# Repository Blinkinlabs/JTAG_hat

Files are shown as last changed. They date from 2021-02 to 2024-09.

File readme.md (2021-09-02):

# JTAG Hat

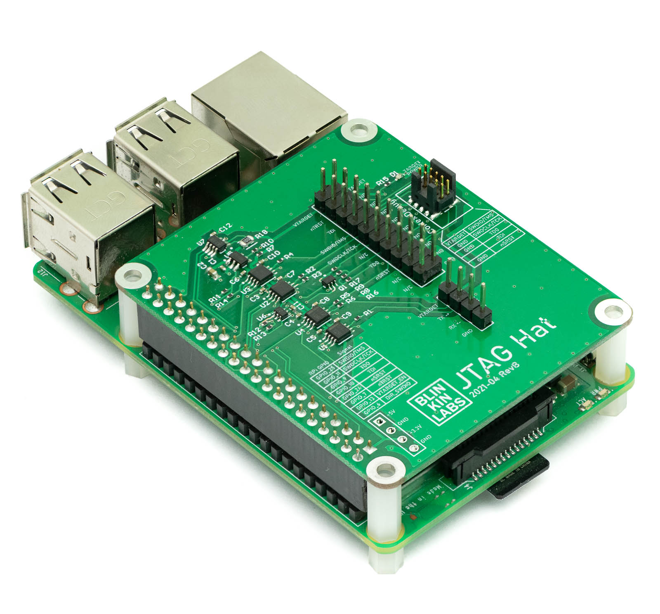
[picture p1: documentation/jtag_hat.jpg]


Convert your Raspberry Pi 2/3/4 into a networked JTAG debugger!

The JTAG Hat is designed to work with [OpenOCD](http://openocd.org/), and provides a .05" 10-pin [Cortex Debug Connector](https://documentation-service.arm.com/static/5fce6c49e167456a35b36af1), with pins to support debugging devices with either a JTAG (TCK/TMS/TDI/TDO) or SWD (SWDIO/SWDCLK) programming interface. A traditional .1, 20-pin JTAG header is also provided, which can be used with 0.1" jumper wires for more flexibiity.

Features:
*    Level-shifted JTAG / SWD programming interface, supports 1.8V to 5V targets
*    Designed to work with OpenOCD, which supports debugging a large number of devices (STM32, ESP32, etc)
*    Selectable target power, to power your device from the RPi 3.3V suppy
*    Hardware reset (both SRST and TRST) via a pull-down transistor
*    Level-shifted UART interface connected to RPi serial port
*    Built-in voltage and current measurement of target device

[Get one here (US)](https://shop.blinkinlabs.com/collections/development-tools/products/jtag-hat) or [here (EU/rest of world)](https://shop-nl.blinkinlabs.com/collections/development-tools/products/jtag-hat), or make one yourself- all design files are in this repository.

## Setup

1. Use [Rasbperry Pi Imager](https://www.raspberrypi.org/software/) to image the micro SD card with 'Raspberry Pi OS Lite'

2. Before clicking 'write', enter the secret 'advanced options' menu by holding down Ctrl+Shift+X. Change the following settings:
   1. Set the hostname to 'jtaghat'
   2. Enable SSH, and set a password for the 'pi' user
   3. Enable WiFi, and set the SSID and password for your WiFi netowrk. Set the Wifi country to your country.
   4. Set the locale settings to your current location.
   5. Check the option to skip the first-run wizard.

2. Boot the pi, and check the router to determine the IP address, then SSH into it

3. Update packages and install git:
```
sudo apt update
sudo apt upgrade -y
sudo apt install -y git autoconf libtool libusb-1.0-0-dev screen telnet
```

4. Download and build the master branch of OpenOCD:
```
git clone https://git.code.sf.net/p/openocd/code openocd-code
cd openocd-code

./bootstrap
./configure --enable-sysfsgpio --enable-bcm2835gpio
make -j6
sudo make install
```

## Use it

1. Connect using the Arm Cortex Debug connector
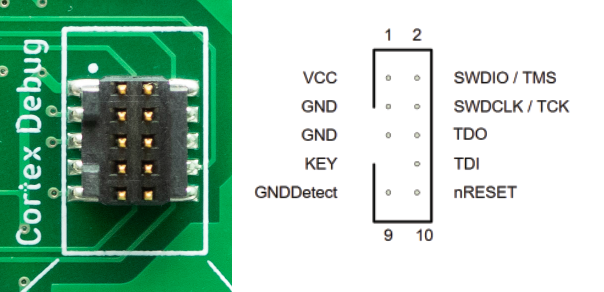
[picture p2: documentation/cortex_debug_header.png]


This connector works well if your target board has one of these connectors. This connector supports both JTAG and SWD connection modes, and has a reset pin controlled by 'srst'. It's very tidy:

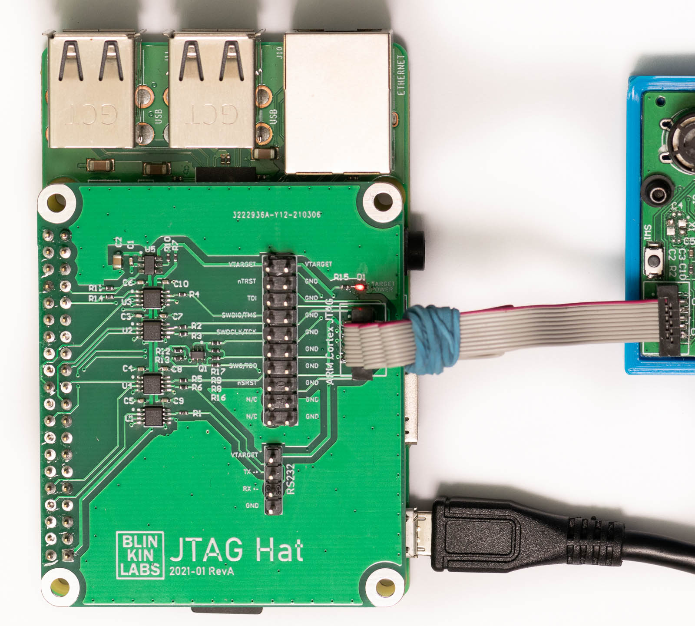
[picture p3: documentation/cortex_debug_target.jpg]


-or-

2.  Connect using the 20-pin 'legacy' connector
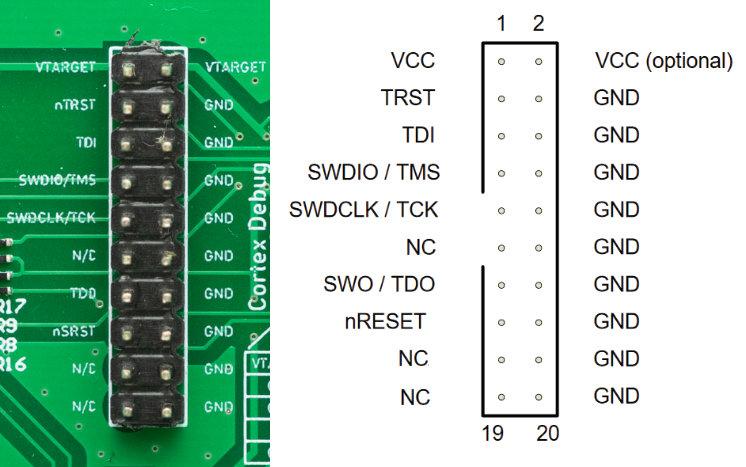
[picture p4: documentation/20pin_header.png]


This connector works well if your target board has one of these connectors, or if you want to use jumper wires to connect to .1" headers on a board. This connector supports both JTAG and SWD connection modes, and has a reset pin controlled by 'srst', as well as one  controlled by 'trst'. Note that some of the optional signals (RTCK, DBGRQ, DBACK) are not supported by OpenOCD, and are not present on this connector.

For SWD mode, you'll need at least GND,SWDIO, and SWDCLK. For JTAG mode, you'll need GND,TCK,TDI,TDO, and TMS.

3. (optional) Enable target power

The JTAG Hat can provide an optional 3.3V, 500mA* supply to the target. To enable it, RPi GPIO13 should be set to an output:
```
echo 13 > /sys/class/gpio/export
echo out > /sys/class/gpio/gpio13/direction
echo 1 > /sys/class/gpio/gpio13/value
```

Similarly, to turn it off:
```
echo 0 > /sys/class/gpio/gpio13/value
```
Note: If your target board is already powered, do not enable target power! The red LED on the board will light up when the target power voltage is present.

4. Start an OpenOCD session for an STM32F0 target:
```
sudo openocd -f interface/jtag_hat_rpi2.cfg \
             -c "bindto 0.0.0.0; transport select swd" \
             -c "reset_config srst_only" \
             -c "adapter speed 1000" \
             -f target/stm32f0x.cfg
```

Now you can connect to the server using GDB, and flash new code, dump things, etc.

## Sensing load current

The hat includes an INA219 current sensor, which can be used to monitor the target power usage if powered through the Pi, and the target voltage if the target is self-powered. To use it:

1. Use 'sudo raspi-config', and under the 'Interfacing Options' menu, enable the I2C interface.

2. Install the [Pi INA219 library](https://github.com/chrisb2/pi_ina219/blob/master/README.md):
```
    sudo apt install python3-pip
    pip3 install pi-ina219
```

3. Create a new file called 'sense_current.py', and copy the following into it:

```
#!/usr/bin/env python3
from ina219 import INA219
from ina219 import DeviceRangeError
SHUNT_OHMS = 0.1
def read():
   ina = INA219(SHUNT_OHMS)
   ina.configure()
   print("Bus Voltage: {:.3f} V".format(ina.voltage()))
   try:
       print("Bus Current: {:.3f} mA".format(ina.current()))
       print("Power: {:.3f} mW".format(ina.power()))
       print("Shunt voltage: {:.3f} mV".format(ina.shunt_voltage()))
   except DeviceRangeError as e:
       # Current out of device range with specified shunt resister
       print(e)
if __name__ == "__main__":
   read()
```

4. Make the script executable, then run it:
```
chmod +x sense_current.py
./sense_current.py
    
Bus Voltage: 3.280 V
Bus Current: 95.000 mA
Power: 311.707 mW
Shunt voltage: 9.510 mV
```

Note that the current measurement includes the power used by the target voltage indicator LED, as well as the level translation buffers.

## UART header

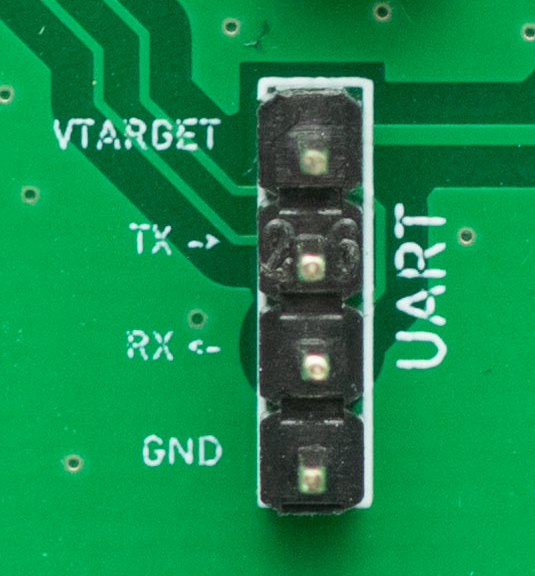
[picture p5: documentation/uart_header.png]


The JTAG Hat also has a level-translated UART header. The UART situation on Raspberry Pi is a [little complicated](https://www.raspberrypi.org/documentation/configuration/uart.md), so a little configuration is needed to make this pin work.

### Setup

1. Disable Bluetooth (Raspberry Pi 3,4 only): On the Raspberry Pi 3 and 4, the UART is normally connected to the Bluetooth chip, so we'll first need to disable that to free up the pins. Add the following to /boot/config.txt:
```
dtoverlay=disable-bt
```
2. Enable the serial port and configure it for general purpose use. Run 'sudo raspi-config', then select '3 Interface Options', 'P6 Serial Port'. Choose 'No' to disable the login shell over serial, then 'Yes' to enable hardware serial. Choose 'Ok' to confirm the settings, then 'Finish' to apply them. Choose 'Yes' to reboot the system and apply the changes.

3. Once the system reboots, check that the serial port is configured correctly:
```
ls -l /dev/serial0
```
This should now point to ttyAM0:
```
lrwxrwxrwx 1 root root 7 Mar 24 15:10 /dev/serial0 -> ttyAMA0
```

### Using the serial port

Once the serial port is configured, it should be ready for use. You can test it using screen:
```
screen /dev/serial0 115200
```

Tip: Make sure to connect a ground wire between the JTAG Hat and the target board.

Tip: Make sure Vtarget is enabled, otherwise the serial port buffers won't work.

## Hardware design

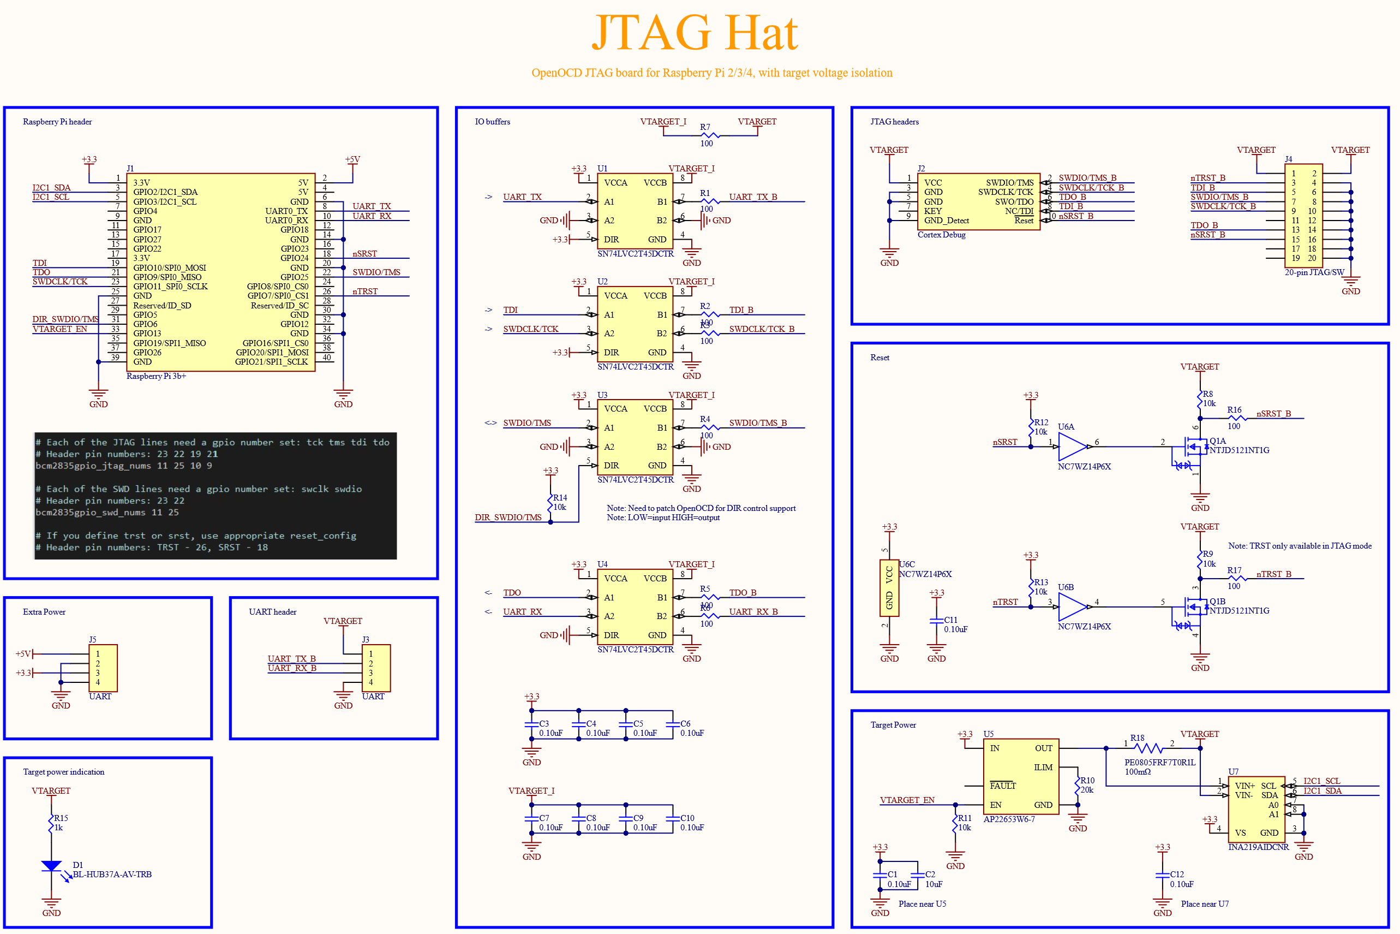
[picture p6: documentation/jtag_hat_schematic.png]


This repository contains the Altium [source files](https://github.com/Blinkinlabs/JTAG_hat/tree/main/pcb), as well as the gerbers used for production.

## License

Copyright Blinkinlabs 2021. The board design is [licensed under CERN-OHL-P v2](https://cern.ch/cern-ohl) and documentation is released under [Attribution-ShareAlike 4.0 International](https://creativecommons.org/licenses/by-sa/4.0/legalcode)

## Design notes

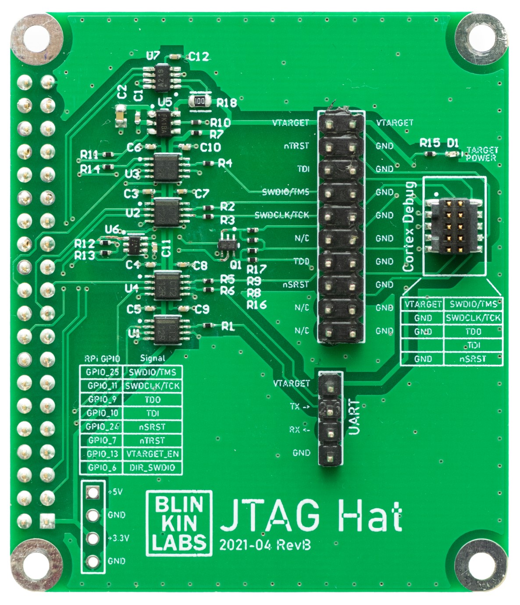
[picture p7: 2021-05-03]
documentation/jtag_hat_top_view.jpg

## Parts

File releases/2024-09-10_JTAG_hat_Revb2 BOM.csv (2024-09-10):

Designator | Quantity | Comment | Description | Manufacturer 1 | Manufacturer Part Number 1 | Supplier 1 | Supplier Part Number 1 | Supplier 2 | Supplier Part Number 2 | Pins | Package / Case | Footprint | Library Name
C1, C3, C4, C5, C6, C7, C8, C9, C10, C11, C12 | 11 | 0.10uF | CAP CER 0.1UF 16V X5R 0402 | Murata | GRM155R61C104KA88D | Digikey | 490-5415-1-ND |  |  | 2 |  | CAPC1005X06L | blinkinlabs.DbLib
C2 | 1 | 10uF | CAP CER 10UF 10V X7R 0805 | Murata Electronics North America | GRM21BR71A106KE51L | DigiKey | 490-3905-1-ND |  |  | 2 |  | CAPC2012X10L | blinkinlabs.DbLib
D1 | 1 | BL-HUB37A-AV-TRB | LED, 0402, Super Red, 50mcd@20mA, 627~637nm | BrtLed | BL-HUB37A-AV-TRB | LCSC | C165980 |  |  | 2 |  | BL-Hxx37A-AV-TRB | blinkinlabs.DbLib
J1 | 1 | SC0073 | Raspberry Pi shield Header | Raspberry Pi | SC0073 | Digikey | 2648-SC0073-ND |  |  | 40 |  | RaspberryPi_Connector | blinkinlabs.DbLib
J2 | 1 | FTSH-105-01-L-DV-K-TR | 1.27mm 2 10P -55?~+125? Standing paste 3.4A SMD,P=1.27mm Board-to-Board and Backplane Connector ROHS | Samtec | FTSH-105-01-L-DV-K-TR | LCSC | C448647 | Digikey | SAM13165CT-ND | 10 |  | FTSH-105-01-L-DV-K-TR | blinkinlabs.DbLib
Q1 | 1 | NTJD5121NT1G | Mosfet Array 60V 295mA 250mW Surface Mount SC-88/SC70-6/SOT-363 | ON Semiconductor | NTJD5121NT1G | Digikey | NTJD5121NT1GOSCT-ND | LCSC | C15215 | 6 |  | FP-419B-02-MFG | blinkinlabs.DbLib
R1, R2, R3, R4, R5, R6, R7, R16, R17 | 9 | 100 | RES SMD 100 OHM 5% 1/10W 0402 | Panasonic | ERJ-2GEJ101X | DigiKey | P100JCT-ND |  |  | 2 |  | ERJ2G(0402)_L | blinkinlabs.DbLib
R8, R9, R11, R12, R13, R14 | 6 | 10k | RES SMD 10K OHM 5% 1/5W 0402 | Panasonic | ERJ-PA2J103X | Digikey | P17199CT-ND |  |  | 2 |  | ERJ2G(0402)_L | blinkinlabs.DbLib
R10 | 1 | 20k | RES SMD 20K OHM 1% 1/10W 0402 | Panasonic Electronic Components | ERJ-2RKF2002X | Digikey | P20.0KLCT-ND |  |  | 2 |  | ERJ2G(0402)_L | blinkinlabs.DbLib
R15 | 1 | 1k | RES SMD 1K OHM 5% 1/10W 0402 | Panasonic | ERJ2GEJ102X- | Digikey | P1.0KJCT-ND |  |  | 2 |  | ERJ2G(0402)_L | blinkinlabs.DbLib
R18 | 1 | CS05W4F100LT5E | 250mW Thick Film Resistors 500V ±1% 100mO 0805 Chip Resistor - Surface Mount ROHS | UNI-ROYAL | CS05W4F100LT5E | LCSC | C474291 |  |  | 2 |  | ERJ6G(0805)_N | blinkinlabs.DbLib
U1, U2, U3, U4 | 4 | SN74LVC2T45DCTR | Voltage Level Translator Bidirectional 1 Circuit 2 Channel 420Mbps SM8 | Texas Instruments | SN74LVC2T45DCTR | Digikey | 296-16845-1-ND | LCSC | C22672 | 8 |  | FP-DCT0008A-MFG | blinkinlabs.DbLib
U5 | 1 | AP22653W6-7 | LOAD SWITCH,SOT26,T&R,3K | Diodes | AP22653W6-7 | Digikey | 31-AP22653W6-7TR-ND | LCSC | C2158037 | 6 |  | SOT95P280X145-6N-5 | blinkinlabs.DbLib
U6 | 1 | NC7WZ14P6X | Inverter IC 2 Channel Schmitt Trigger SC-88 (SC-70-6) | ON Semiconductor / Fairchild | NC7WZ14P6X | DigiKey | NC7WZ14P6XCT-ND | LCSC | C19829571 | 6 |  | TSOP65P210X110-6N | blinkinlabs.DbLib
U7 | 1 | INA219AID | Current Monitor Regulator High-Side 10mA 8-SOIC | Texas Instruments | INA219AID | Digikey | 296-33291-5-ND | LCSC | C138706 | 8 |  | D0008A_N | blinkinlabs.DbLib
J3 | 1 | UART | Header, 4-Pin |  |  |  |  |  |  | 4 |  | HDR1X4 | Miscellaneous Connectors.IntLib
J4 | 1 | 20-pin JTAG/SW |  |  |  |  |  |  |  | 20 |  | HDR2X10 | Miscellaneous Connectors.IntLib
J5 | 1 | POWER | Header, 4-Pin |  |  |  |  |  |  | 4 |  | HDR1X4 | Miscellaneous Connectors.IntLib

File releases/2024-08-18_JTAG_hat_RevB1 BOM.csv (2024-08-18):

Designator | Quantity | Comment | Description | Manufacturer 1 | Manufacturer Part Number 1 | Supplier 1 | Supplier Part Number 1 | Supplier 2 | Supplier Part Number 2 | Pins | Package / Case | Footprint | Library Name
Q1 | 1 | NTJD5121NT1G | MOSFET 2N-CH 60V 0.295A SOT363 |  |  |  |  |  |  | 6 |  | FP-419B-02-MFG | Altium Content Vault
R18 | 1 | PE0805FRF7T0R1L | METAL CURRENT SENSOR 0805 1% 100 | Yageo | PE0805FRF7T0R1L | Farnell | 4149061 | Farnell | 4149061RL | 2 |  | FP-PE0805L-0R051-0R910-MFG | Altium Content Vault
U1, U2, U3, U4 | 4 | SN74LVC2T45DCTR | IC TRNSLTR BIDIRECTIONAL SM8 | Texas Instruments | SN74LVC2T45DCTR | Digikey | 296-16845-1-ND | Digikey | 296-16845-2-ND | 8 |  | FP-DCT0008A-MFG | Altium Content Vault
U6 | 1 | NC7WZ14P6X | Tiny Logic(R) UHS Dual Inverter with Schmitt Trigger Inputs, 1.65 to 5.5 V, -40 to 85 degC, 6-Pin SOT23 (SC70), RoHS, Tape and Reel | ON Semiconductor / Fairchild | NC7WZ14P6X | Farnell | 1417668 | Farnell | 1417668RL | 6 | 6-TSSOP,SC-88,SOT-363 | FAIR-SC70-6_V | Altium Content Vault
U7 | 1 | INA219AID | Zero-Drift, Bi-Directional Current / Power Monitor, 3 to 5.5 V, -40 to 125 degC, 8-pin SOIC (D8), Green (RoHS & no Sb/Br) | Texas Instruments | INA219AID | Digikey | 296-33291-5-ND | Mouser | 595-INA219AID | 8 |  | D0008A_N | Altium Content Vault
D1 | 1 | BL-HUB37A-AV-TRB | LED, 0402, Super Red, 50mcd@20mA, 627~637nm |  |  |  |  |  |  | 2 |  | BL-Hxx37A-AV-TRB | Blinkinlabs.IntLib
J1 | 1 | Raspberry Pi 3b+ | Raspberry Pi shield Header |  |  |  |  |  |  | 40 |  | RaspberryPi_Connector | Blinkinlabs.IntLib
J2 | 1 | Cortex Debug | Arm Cortex 10-pin JTAG connector |  |  |  |  |  |  | 10 |  | 1.27mm 2x5 SMD Header | Blinkinlabs.IntLib
U5 | 1 | AP22653W6-7 | LOAD SWITCH,SOT26,T&R,3K |  |  |  |  |  |  | 6 |  | SOT95P280X145-6N-5 | Blinkinlabs.IntLib
C1, C3, C4, C5, C6, C7, C8, C9, C10, C11, C12 | 11 | 0.10uF | CAP CER 0.1UF 10V X5R 0402 |  |  |  |  |  |  | 2 | 0402 (1005 Metric) | CAPC1005X06L | cap_murata.DbLib
C2 | 1 | 10uF | CAP CER 10UF 10V X7R 0805 |  |  |  |  |  |  | 2 | 0805 (2012 Metric) | CAPC2012X10L | cap_murata.DbLib
J3, J5 | 2 | UART | Header, 4-Pin |  |  |  |  |  |  | 4 |  | HDR1X4 | Miscellaneous Connectors.IntLib
J4 | 1 | 20-pin JTAG/SW |  |  |  |  |  |  |  | 20 |  | HDR2X10 | Miscellaneous Connectors.IntLib
R1, R2, R3, R4, R5, R6, R7, R16, R17 | 9 | 100 | RES SMD 100 OHM 5% 1/10W 0402 |  |  |  |  |  |  | 2 | 0402 (1005 Metric) | ERJ2G(0402)_L | res_panasonic_erj_xls.DbLib
R8, R9, R11, R12, R13, R14 | 6 | 10k | RES SMD 10K OHM 5% 1/5W 0402 |  |  |  |  |  |  | 2 | 0402 (1005 Metric) | ERJ2G(0402)_L | res_panasonic_erj_xls.DbLib
R10 | 1 | 20k | RES SMD 20K OHM 1% 1/10W 0402 |  |  |  |  |  |  | 2 | 0402 (1005 Metric) | ERJ2G(0402)_L | res_panasonic_erj_xls.DbLib
R15 | 1 | 1k | RES SMD 1K OHM 5% 1/10W 0402 |  |  |  |  |  |  | 2 | 0402 (1005 Metric) | ERJ2G(0402)_L | res_panasonic_erj_xls.DbLib

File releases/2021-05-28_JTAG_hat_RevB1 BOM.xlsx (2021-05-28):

Designator | Comment | Manufacturer | PartNumber | Digi-Key Part Number | LCSC PartNumber | Description | Pins | Quantity | Model:Footprint | Case/Package
C1, C3, C4, C5, C6, C7, C8, C9, C10, C11, C12 | 0.10uF | Murata Electronics North America | GRM155R61A104KA01D | 490-1318-1-ND |  | CAP CER 0.1UF 10V X5R 0402 | 2 | 11 |  | 0402
C2 | 10uF | Murata Electronics North America | GRM21BR71A106KE51L | 490-3905-1-ND |  | CAP CER 10UF 10V X7R 0805 | 2 | 1 |  | 0805
D1 | BL-HUB37A-AV-TRB | BrtLed(佰鸿) | BL-HUB37A-AV-TRB |  | C165980 | LED, 0402, Super Red, 50mcd@20mA, 627~637nm | 2 | 1 | 0402 LED, generic
J1 | Raspberry Pi 3b+ |  |  |  |  | Raspberry Pi shield Header | 40 | 1
J2 | Cortex Debug | Unknown/Generic | unknown/Generic |  |  | Arm Cortex 10-pin JTAG connector | 10 | 1
J3, J5 | UART |  |  |  |  | Header, 4-Pin | 4 | 2 | Connector; Header; 4 Position
J4 | 20-pin JTAG/SW |  |  |  |  |  | 20 | 1 | Connector; Header; 10x2 Position
Q1 | NTJD5121NT1G | On Semiconductor |  |  |  | MOSFET 2N-CH 60V 0.295A SOT363 | 6 | 1
R1, R2, R3, R4, R5, R6, R7, R16, R17 | 100 | Panasonic Electronic Components | ERJ-2GEJ101X | P100JCT-ND |  | RES SMD 100 OHM 5% 1/10W 0402 | 2 | 9 |  | 0402
R8, R9, R11, R12, R13, R14 | 10k | Panasonic Electronic Components | ERJ-PA2J103X | P17199CT-ND |  | RES SMD 10K OHM 5% 1/5W 0402 | 2 | 6 |  | 0402
R10 | 20k | Panasonic Electronic Components | ERJ-2RKF2002X | P20.0KLCT-ND |  | RES SMD 20K OHM 1% 1/10W 0402 | 2 | 1 |  | 0402
R15 | 1k | Panasonic Electronic Components | ERJ-2GEJ102X | P1.0KJCT-ND |  | RES SMD 1K OHM 5% 1/10W 0402 | 2 | 1 |  | 0402
R18 | PE0805FRF7T0R1L | Yageo |  |  |  | METAL CURRENT SENSOR 0805 1% 100 | 2 | 1
U1, U2, U3, U4 | SN74LVC2T45DCTR | Texas Instruments |  |  |  | IC TRNSLTR BIDIRECTIONAL SM8 | 8 | 4
U5 | AP22653W6-7 | Diodes Incorporated | AP22653W6-7 |  |  | LOAD SWITCH,SOT26,T&R,3K | 6 | 1 | SOT23, 6-Leads, Body 2.90x2.80mm, Pitch 0.95mm, IPC Medium Density
U6 | NC7WZ14P6X | Fairchild Semiconductor |  |  |  | Tiny Logic(R) UHS Dual Inverter with Schmitt Trigger Inputs, 1.65 to 5.5 V, -40 to 85 degC, 6-Pin SOT23 (SC70), RoHS, Tape and Reel | 6 | 1 | SC70, 6-Leads, Body 2x1.25mm, Pitch 0.65mm
U7 | INA219AID | Texas Instruments | INA219AID |  |  | Zero-Drift, Bi-Directional Current / Power Monitor, 3 to 5.5 V, -40 to 125 degC, 8-pin SOIC (D8), Green (RoHS & no Sb/Br) | 8 | 1 | SOIC, 8-Leads, Body 5x4mm, Pitch 1.27mm, IPC Medium Density

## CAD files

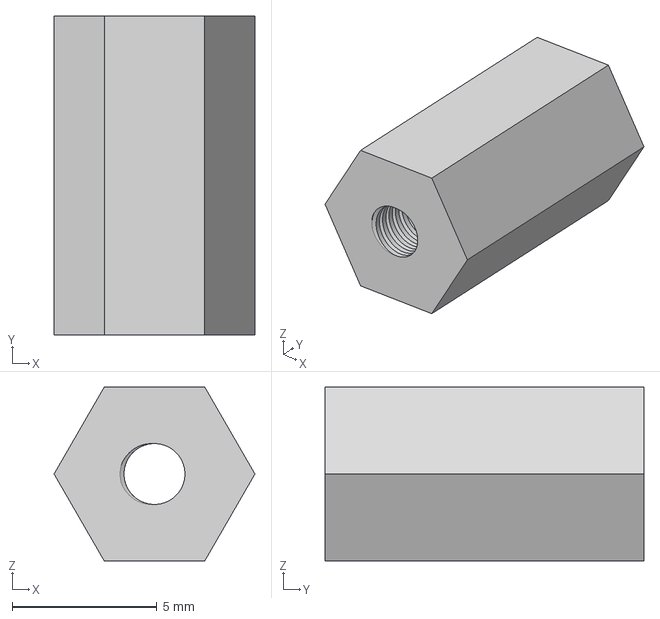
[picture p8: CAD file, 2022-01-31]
releases/2022-01-30 spacer.3mf
6.93 x 11.0 x 6.00 mm

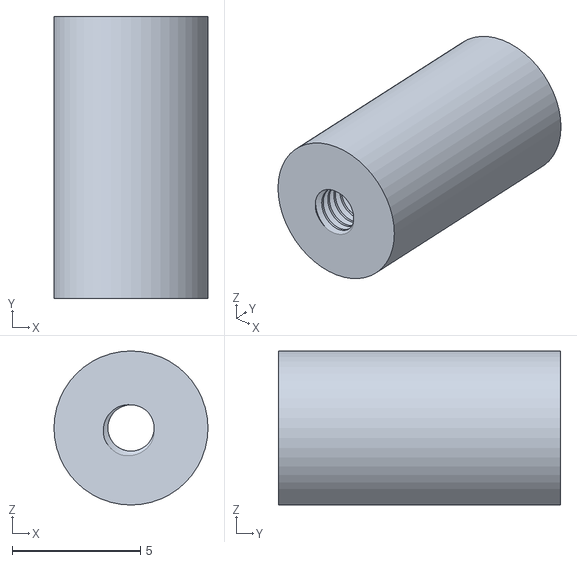
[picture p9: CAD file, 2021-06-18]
releases/2021-05-27_spacer.STL
6.00 x 11.0 x 6.00

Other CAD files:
releases/2022-01-30 spacer v1.f3d

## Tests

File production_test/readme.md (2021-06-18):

# Production test

Script to test that all features of the JTAG-Hat are functional

Required material:

* Raspberry Pi w/patched OpenOCD
* JTAG_Hat (DUT)
* STM32F103RC development board, or board with similar processor that supports both JTAG and SWD programming interfaces
* 2x LED + ~330 ohm resistor, connected in series. Attach one between 3.3V and SRST on the development board, and the other between 3.3V and TRST on the develoment board.
* 10-pin, 1.27mm ribbon cable
* 20-pin 2.54mm ribbon cable
* 20-pin to 10-pin adapter board (if development board only has 20-pin interface)
* 2-pin, 2.54mm jumper

Steps:

1. Boot the raspberry pi
2. Plug a JTAG Hat into the raspberry pi
3. Connect the 2-pin jumper between TX and RX on the UART header
4. Connect the development board to the JTAG_Hat using the 20 pin ribbon cable
5. Run the test script. All 8 tests should pass
6. Observe the reset LEDs. they should flash in an alternating pattern
7. Press Ctrl+C to stop the test program
8. Remove the 20 pin ribbon cable
9. Connect the development board to the JTAG_Hat using the 10 pin ribbon cable
10. Run the test script again. All 8 tests should pass again
11. Observe the reset LEDs. Only the one connected to SRST should be flashing
12. Press Ctrl+C to stop the test program
13. Remove the JTAG_Hat; repeat steps with next JTAG_Hat

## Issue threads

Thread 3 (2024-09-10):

GPIO instructions are out of date for modern Raspbian

cibomahto, 2024-09-10:
With recent Linux kernels, the GPIO numbering scheme has changed. The documentation should be updated.

This is an example of how to find the correct GPIO to turn on target power on a Rasbperry Pi 4:

```
cat /sys/kernel/debug/gpio

echo 525 > /sys/class/gpio/export
echo out > /sys/class/gpio/gpio525/direction
echo 1 > /sys/class/gpio/gpio525/value
```

cibomahto, 2025-07-17:
Here's a gpio config that works with linunxgpio driver on Raspberry Pi 5:

```
cat jtag_hat_rpi5.cfg
# SPDX-License-Identifier: GPL-2.0-or-later
#
# Blinkinlabs JTAG_Hat
#
# https://github.com/blinkinlabs/jtag_hat
#

adapter driver linuxgpiod

# Each of the JTAG lines need a gpio number set: tck tms tdi tdo
# Header pin numbers: 23 22 19 21
adapter gpio tck 11 -chip 0
adapter gpio tms 25 -chip 0
adapter gpio tdi 10 -chip 0
adapter gpio tdo 9 -chip 0

# Each of the SWD lines need a gpio number set: swclk swdio
# Header pin numbers: 23 22
adapter gpio swclk 11 -chip 0
adapter gpio swdio 25 -chip 0

# Direction pin for SWDIO level shifting buffer
adapter gpio swdio_dir 6 -chip 0

# If you define trst or srst, use appropriate reset_config
# Header pin numbers: TRST - 26, SRST - 18

adapter gpio trst 7 -chip 0
#reset_config trst_only

adapter gpio srst 24 -chip 0
#reset_config srst_only

# or if you have both connected
#reset_config trst_and_srst
```

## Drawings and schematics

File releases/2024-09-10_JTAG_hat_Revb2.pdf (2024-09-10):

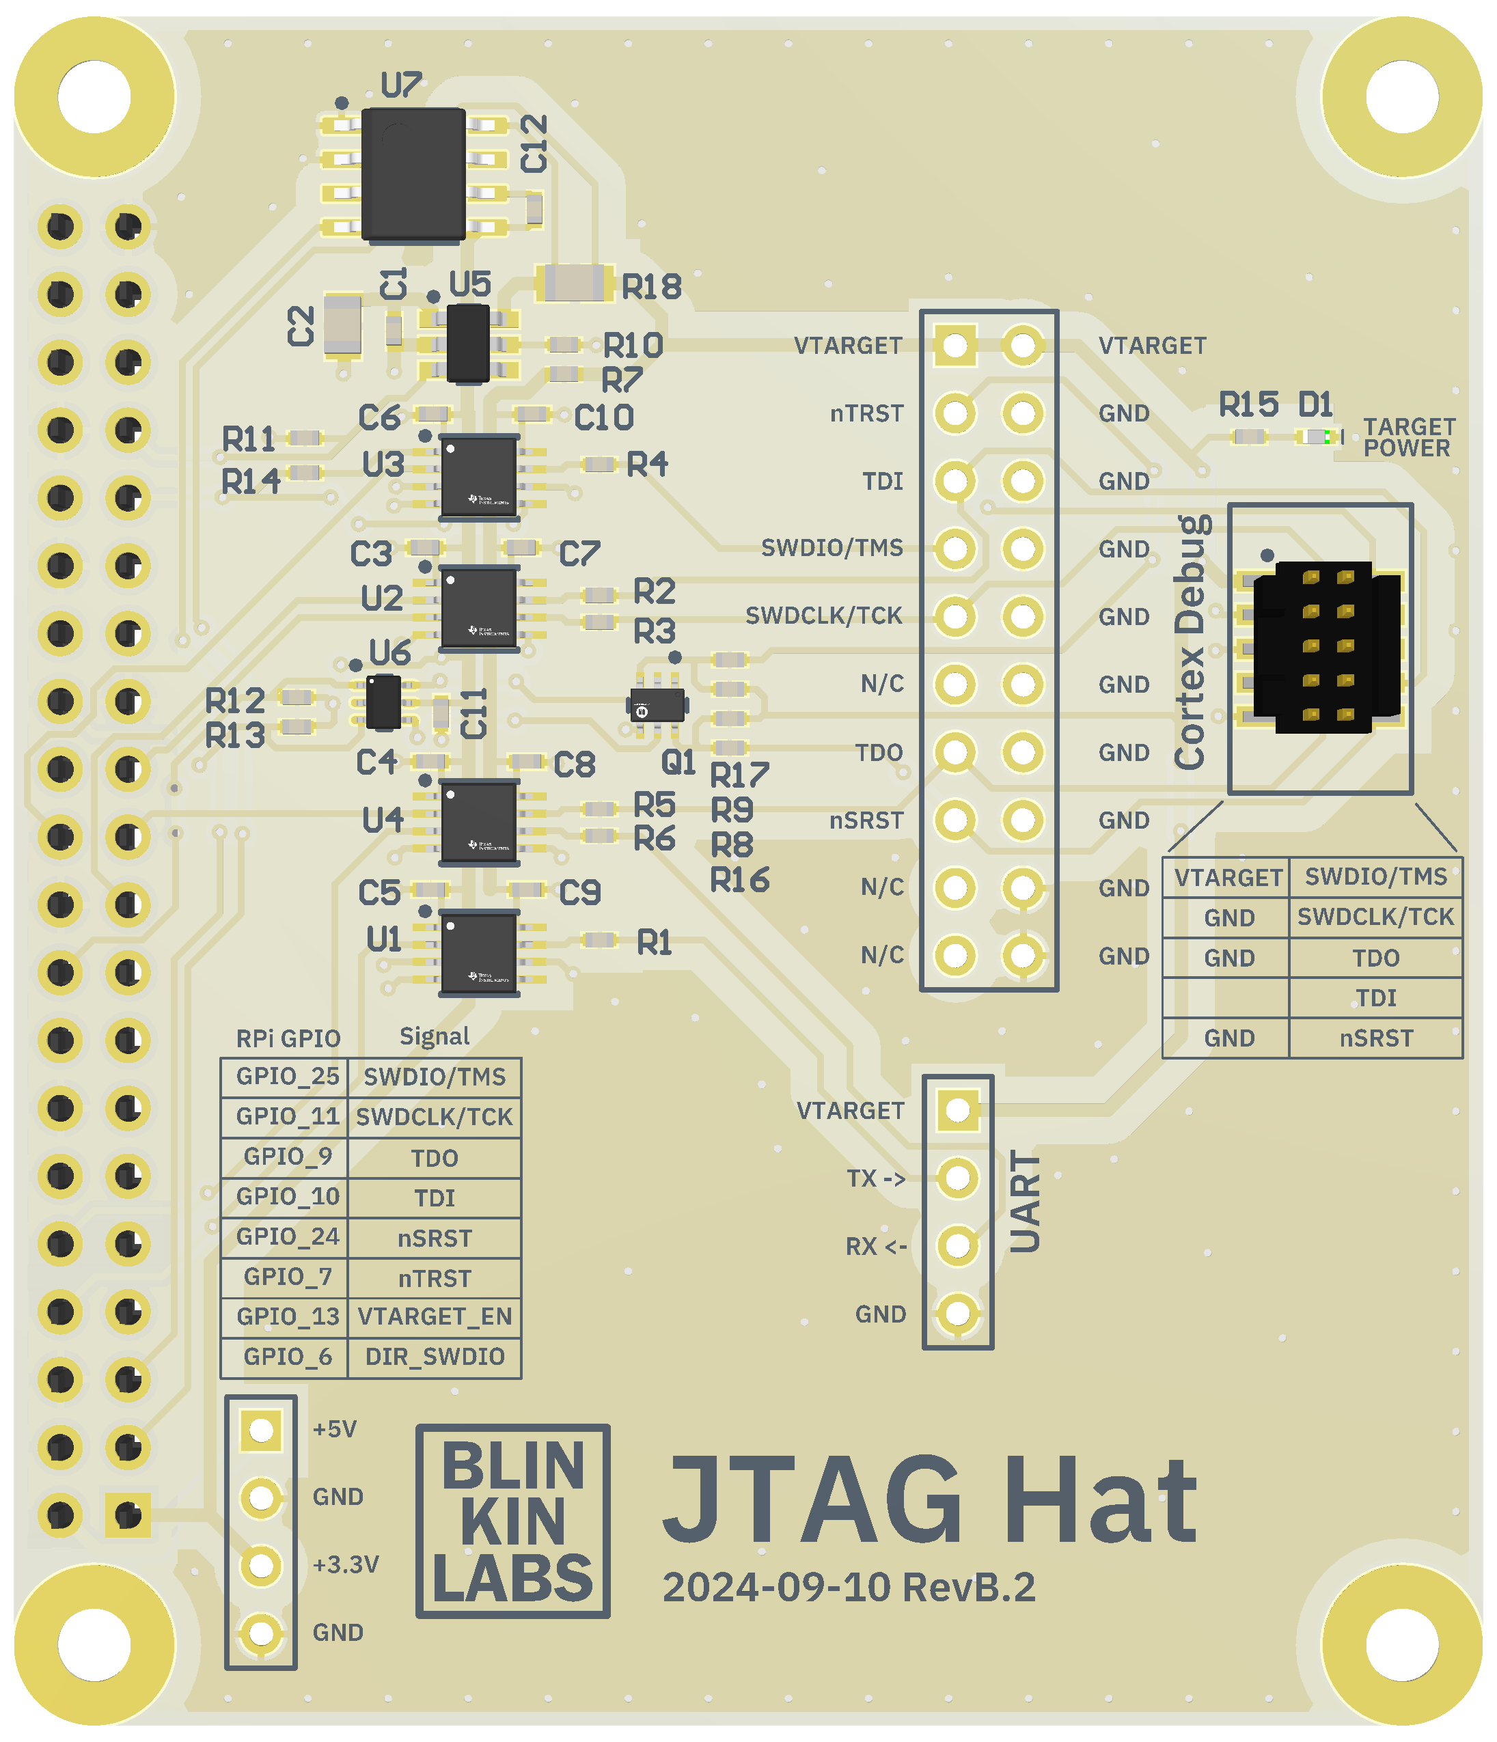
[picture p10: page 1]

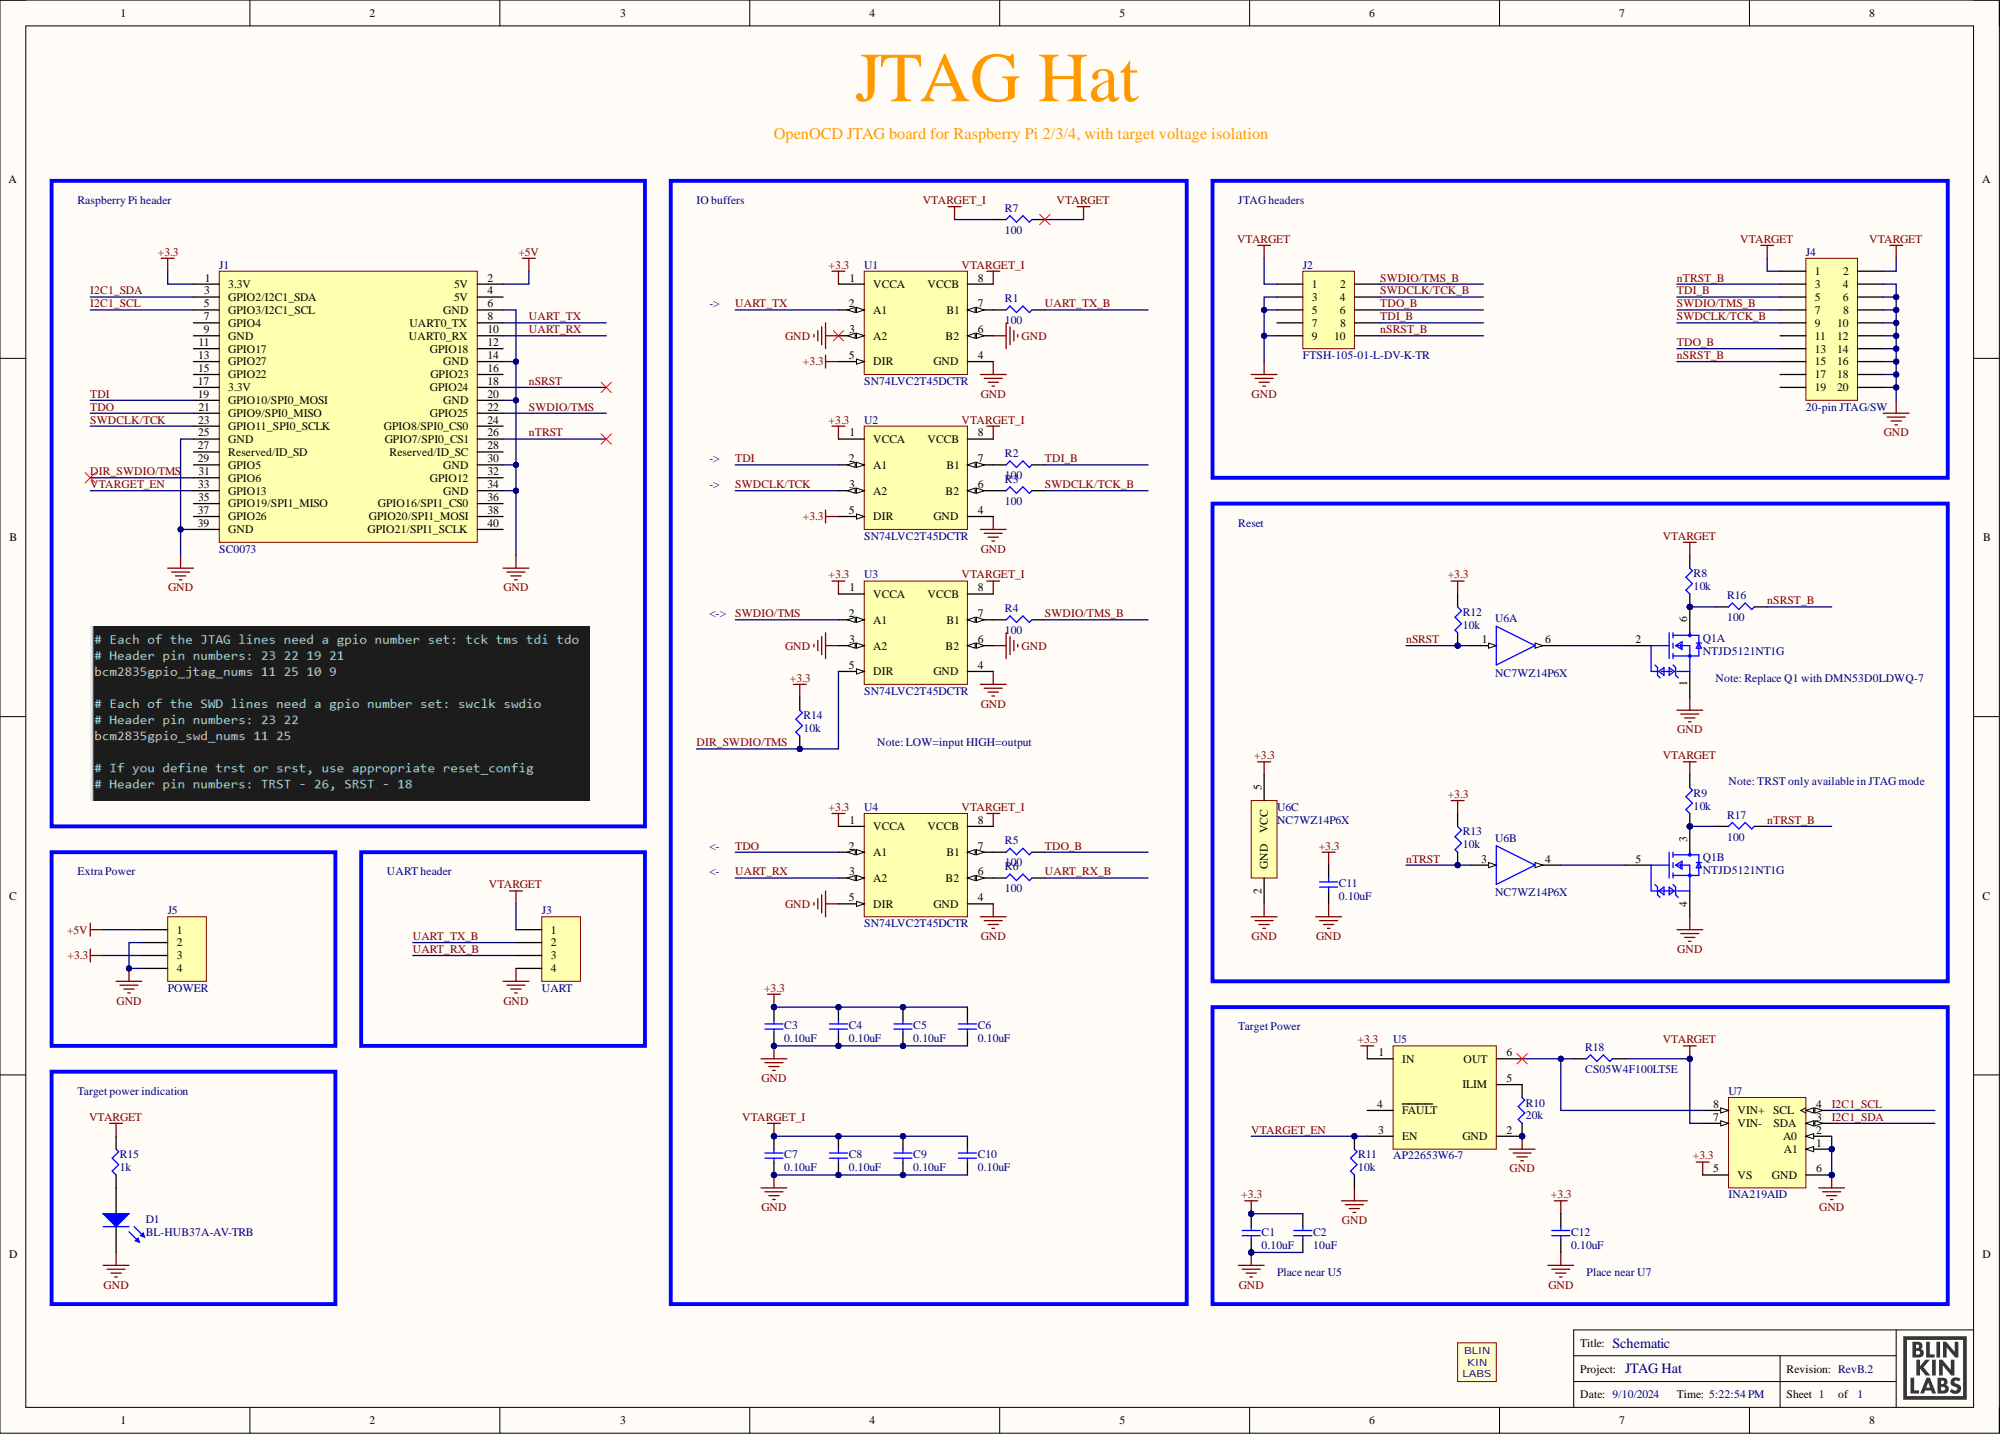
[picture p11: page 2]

G board for Raspberry Pi 2/3/4,

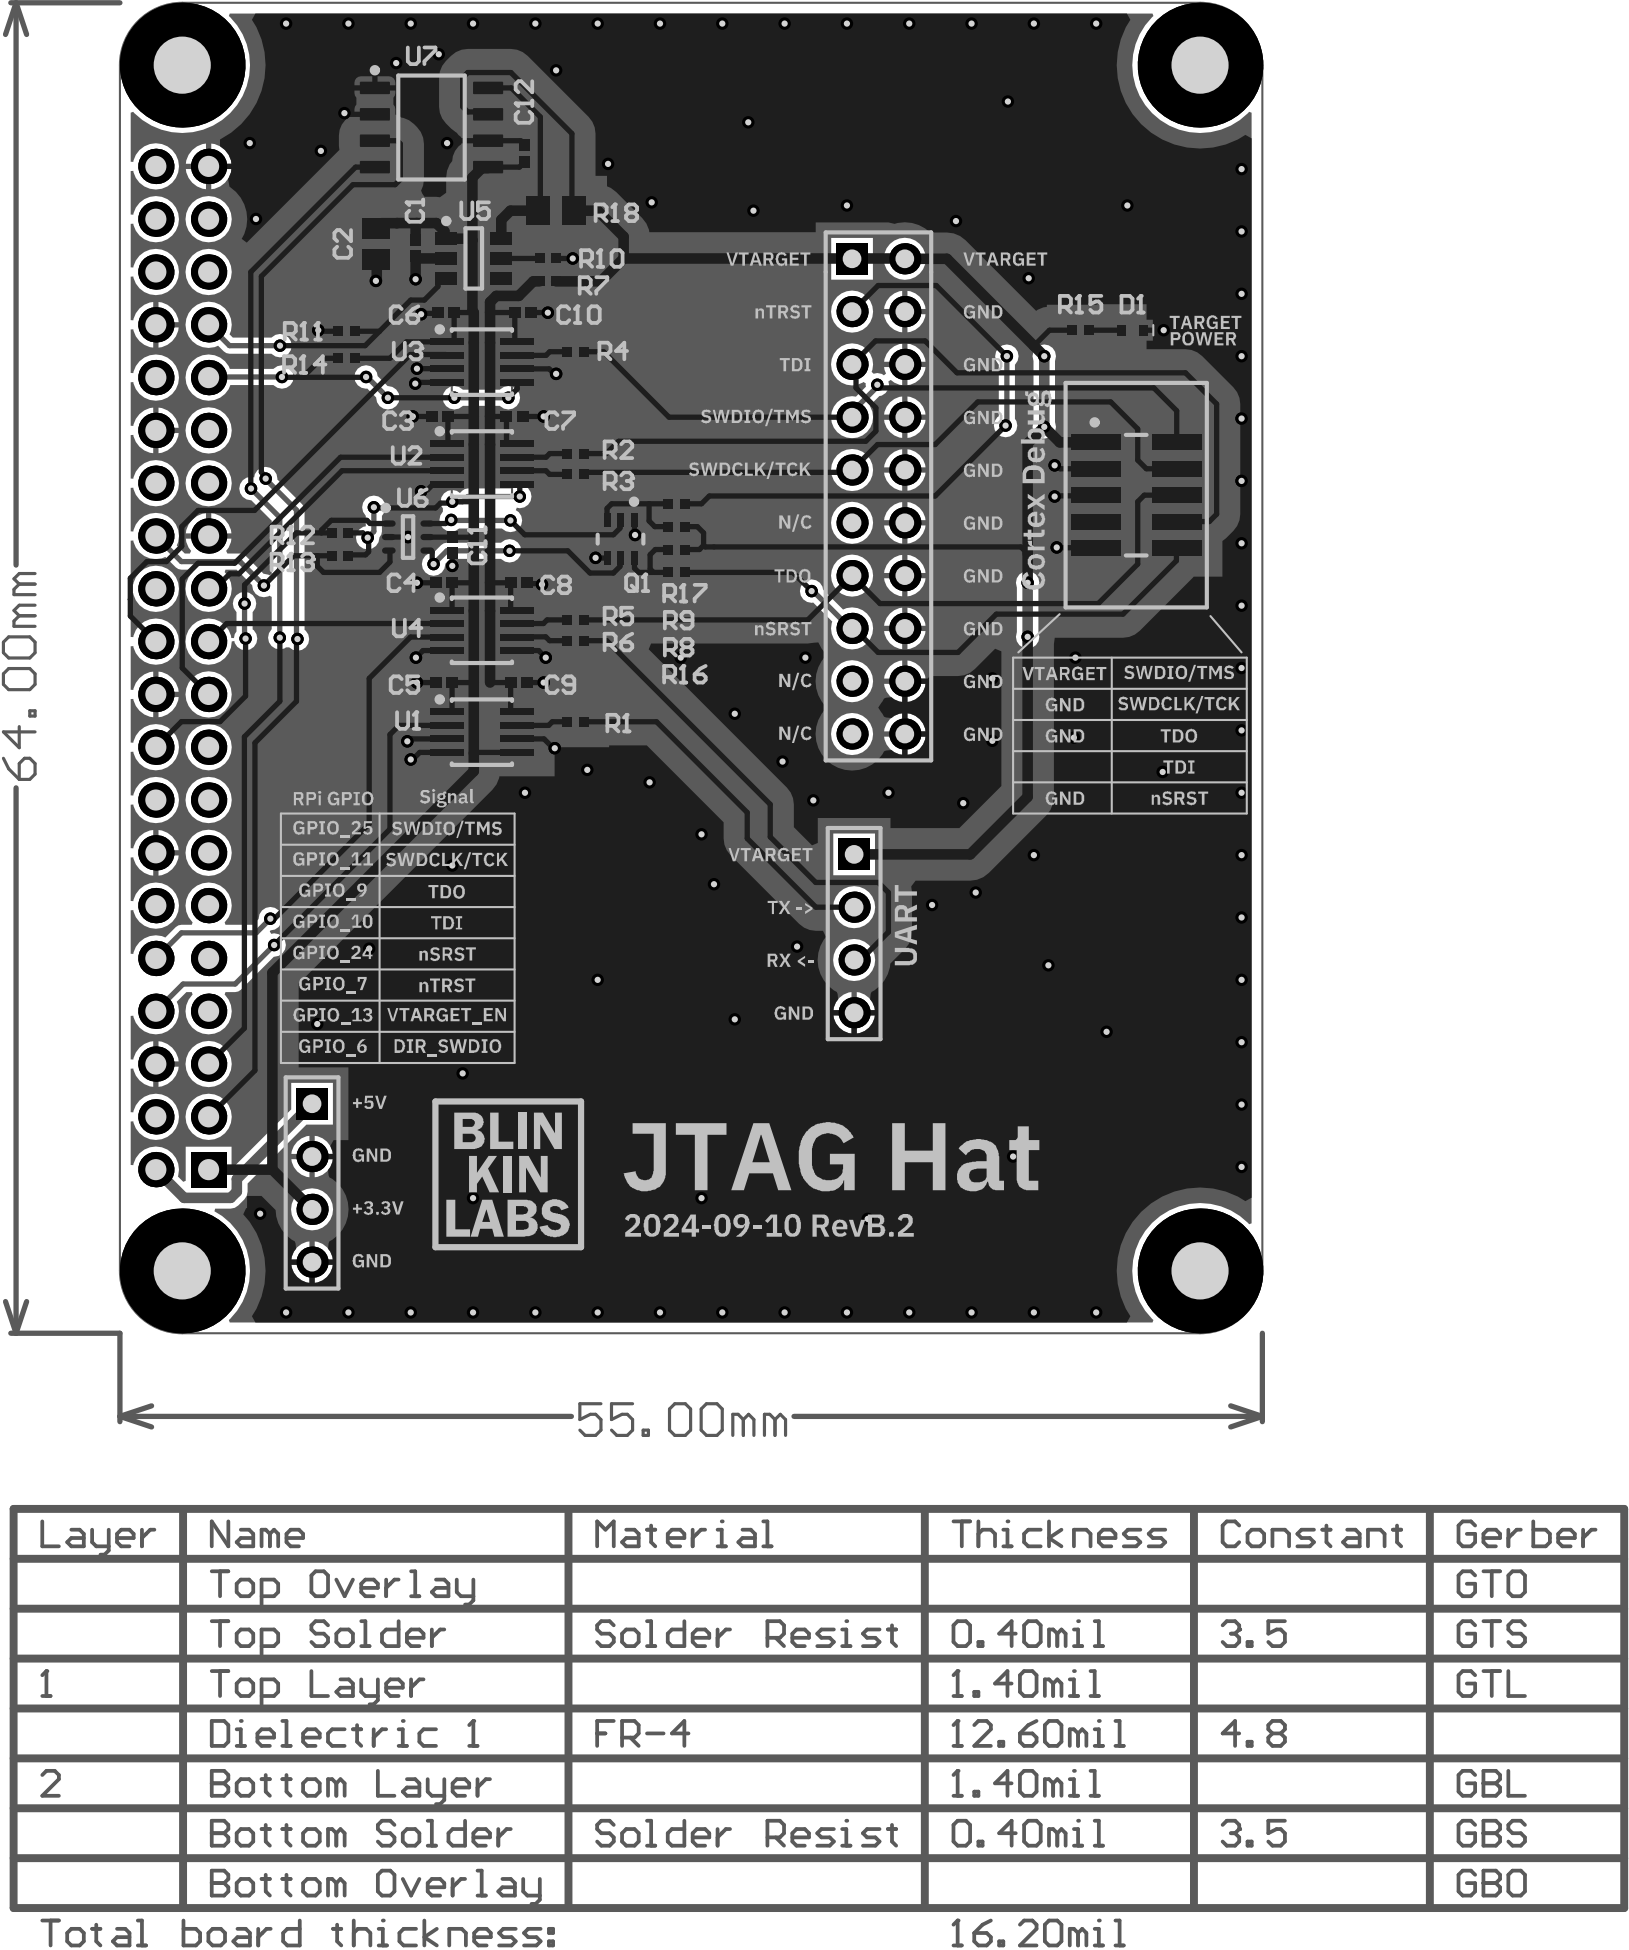
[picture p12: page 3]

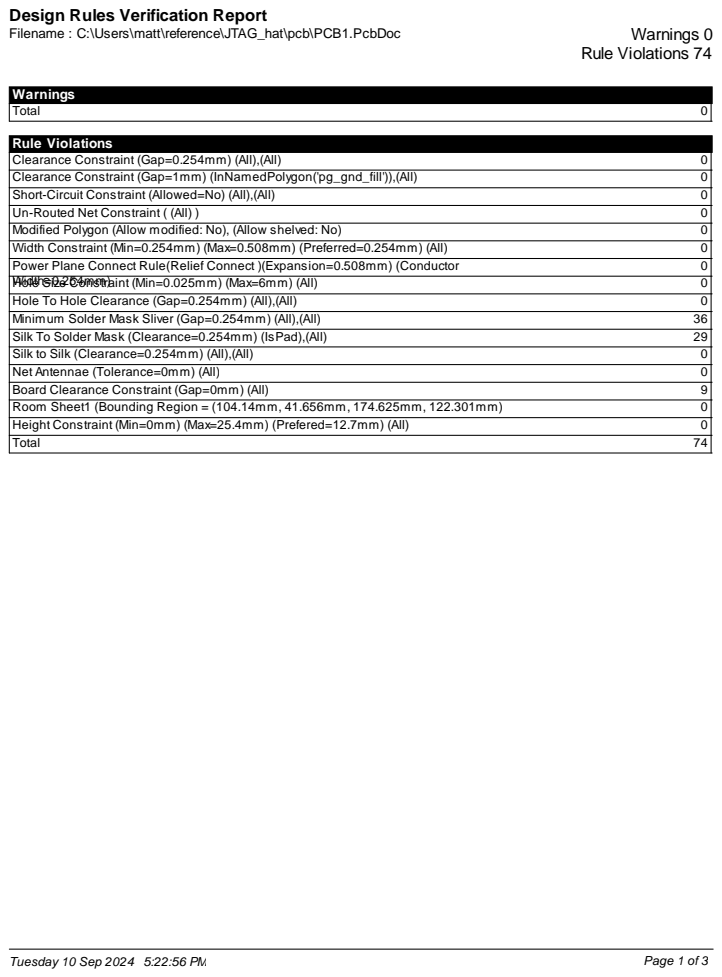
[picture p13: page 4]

Design Rules Verification Report

Rule Violations
Power Plane Connect Rule(Relief Connect )(Expansion=0.508mm) (Conductor
Width=0.254mm)

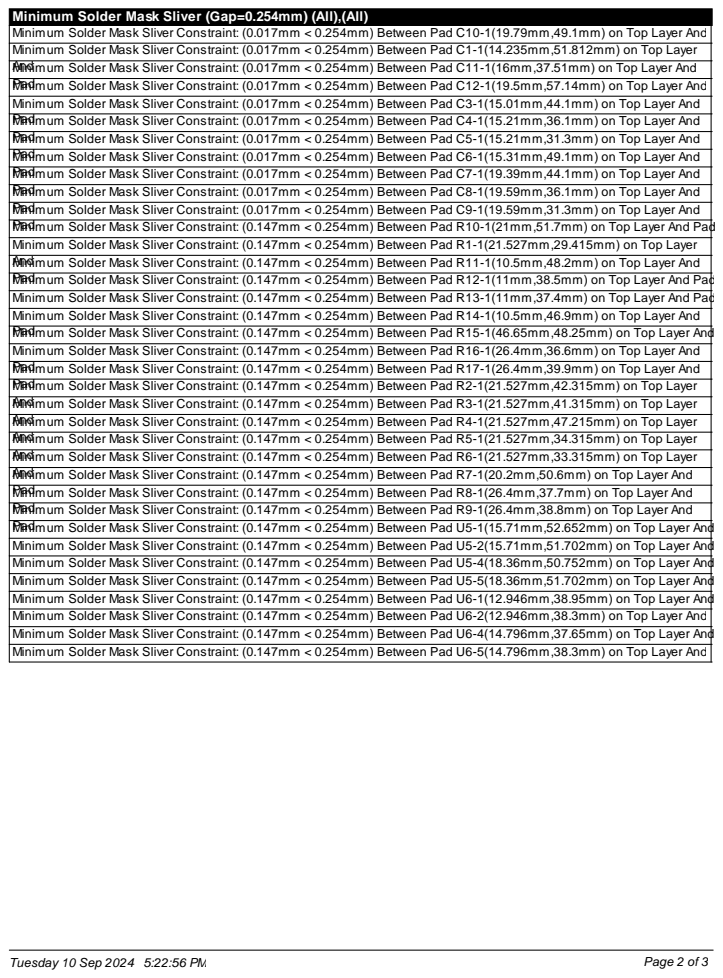
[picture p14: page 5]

Minimum Solder Mask Sliver (Gap=0.254mm) (All),(All)
Minimum Solder Mask Sliver Constraint: (0.017mm < 0.254mm) Between Pad C10-1(19.79mm,49.1mm) on Top Layer And
Minimum Solder Mask Sliver Constraint: (0.017mm < 0.254mm) Between Pad C1-1(14.235mm,51.812mm) on Top Layer
PaMindimum Solder Mask Sliver Constraint: (0.017mm < 0.254mm) Between Pad C12-1(19.5mm,57.14mm) on Top Layer And
Minimum Solder Mask Sliver Constraint: (0.017mm < 0.254mm) Between Pad C3-1(15.01mm,44.1mm) on Top Layer And
PaMindimum Solder Mask Sliver Constraint: (0.017mm < 0.254mm) Between Pad C4-1(15.21mm,36.1mm) on Top Layer And
PaMindimum Solder Mask Sliver Constraint: (0.017mm < 0.254mm) Between Pad C5-1(15.21mm,31.3mm) on Top Layer And
PaMindimum Solder Mask Sliver Constraint: (0.017mm < 0.254mm) Between Pad C6-1(15.31mm,49.1mm) on Top Layer And
PaMindimum Solder Mask Sliver Constraint: (0.017mm < 0.254mm) Between Pad C7-1(19.39mm,44.1mm) on Top Layer And
PaMindimum Solder Mask Sliver Constraint: (0.017mm < 0.254mm) Between Pad C8-1(19.59mm,36.1mm) on Top Layer And
PaMindimum Solder Mask Sliver Constraint: (0.017mm < 0.254mm) Between Pad C9-1(19.59mm,31.3mm) on Top Layer And
PaMindimum Solder Mask Sliver Constraint: (0.147mm < 0.254mm) Between Pad R10-1(21mm,51.7mm) on Top Layer And Pad
Minimum Solder Mask Sliver Constraint: (0.147mm < 0.254mm) Between Pad R1-1(21.527mm,29.415mm) on Top Layer
PaMindimum Solder Mask Sliver Constraint: (0.147mm < 0.254mm) Between Pad R12-1(11mm,38.5mm) on Top Layer And Pad
Minimum Solder Mask Sliver Constraint: (0.147mm < 0.254mm) Between Pad R13-1(11mm,37.4mm) on Top Layer And Pad
Minimum Solder Mask Sliver Constraint: (0.147mm < 0.254mm) Between Pad R14-1(10.5mm,46.9mm) on Top Layer And
PaMindimum Solder Mask Sliver Constraint: (0.147mm < 0.254mm) Between Pad R15-1(46.65mm,48.25mm) on Top Layer And
Minimum Solder Mask Sliver Constraint: (0.147mm < 0.254mm) Between Pad R16-1(26.4mm,36.6mm) on Top Layer And
PaMindimum Solder Mask Sliver Constraint: (0.147mm < 0.254mm) Between Pad R17-1(26.4mm,39.9mm) on Top Layer And
PaMindimum Solder Mask Sliver Constraint: (0.147mm < 0.254mm) Between Pad R2-1(21.527mm,42.315mm) on Top Layer
PaMindimum Solder Mask Sliver Constraint: (0.147mm < 0.254mm) Between Pad R8-1(26.4mm,37.7mm) on Top Layer And
PaMindimum Solder Mask Sliver Constraint: (0.147mm < 0.254mm) Between Pad R9-1(26.4mm,38.8mm) on Top Layer And
PaMindimum Solder Mask Sliver Constraint: (0.147mm < 0.254mm) Between Pad U5-1(15.71mm,52.652mm) on Top Layer And
Minimum Solder Mask Sliver Constraint: (0.147mm < 0.254mm) Between Pad U5-2(15.71mm,51.702mm) on Top Layer And
Minimum Solder Mask Sliver Constraint: (0.147mm < 0.254mm) Between Pad U5-4(18.36mm,50.752mm) on Top Layer And
Minimum Solder Mask Sliver Constraint: (0.147mm < 0.254mm) Between Pad U5-5(18.36mm,51.702mm) on Top Layer And
Minimum Solder Mask Sliver Constraint: (0.147mm < 0.254mm) Between Pad U6-1(12.946mm,38.95mm) on Top Layer And
Minimum Solder Mask Sliver Constraint: (0.147mm < 0.254mm) Between Pad U6-2(12.946mm,38.3mm) on Top Layer And
Minimum Solder Mask Sliver Constraint: (0.147mm < 0.254mm) Between Pad U6-4(14.796mm,37.65mm) on Top Layer And
Minimum Solder Mask Sliver Constraint: (0.147mm < 0.254mm) Between Pad U6-5(14.796mm,38.3mm) on Top Layer And

Mnindimum Solder Mask Sliver Constraint: (0.017mm < 0.254mm) Between Pad C11-1(16mm,37.51mm) on Top Layer And

Mnindimum Solder Mask Sliver Constraint: (0.147mm < 0.254mm) Between Pad R11-1(10.5mm,48.2mm) on Top Layer And

Mnindimum Solder Mask Sliver Constraint: (0.147mm < 0.254mm) Between Pad R3-1(21.527mm,41.315mm) on Top Layer
Mnindimum Solder Mask Sliver Constraint: (0.147mm < 0.254mm) Between Pad R4-1(21.527mm,47.215mm) on Top Layer
Mnindimum Solder Mask Sliver Constraint: (0.147mm < 0.254mm) Between Pad R5-1(21.527mm,34.315mm) on Top Layer
Mnindimum Solder Mask Sliver Constraint: (0.147mm < 0.254mm) Between Pad R6-1(21.527mm,33.315mm) on Top Layer
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

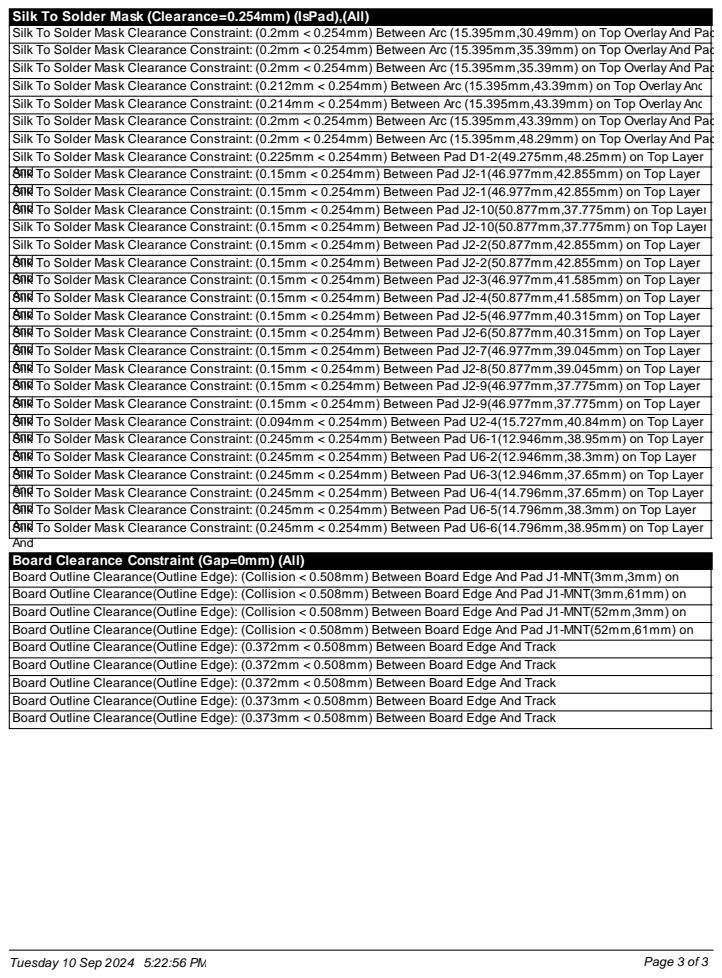
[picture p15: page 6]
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

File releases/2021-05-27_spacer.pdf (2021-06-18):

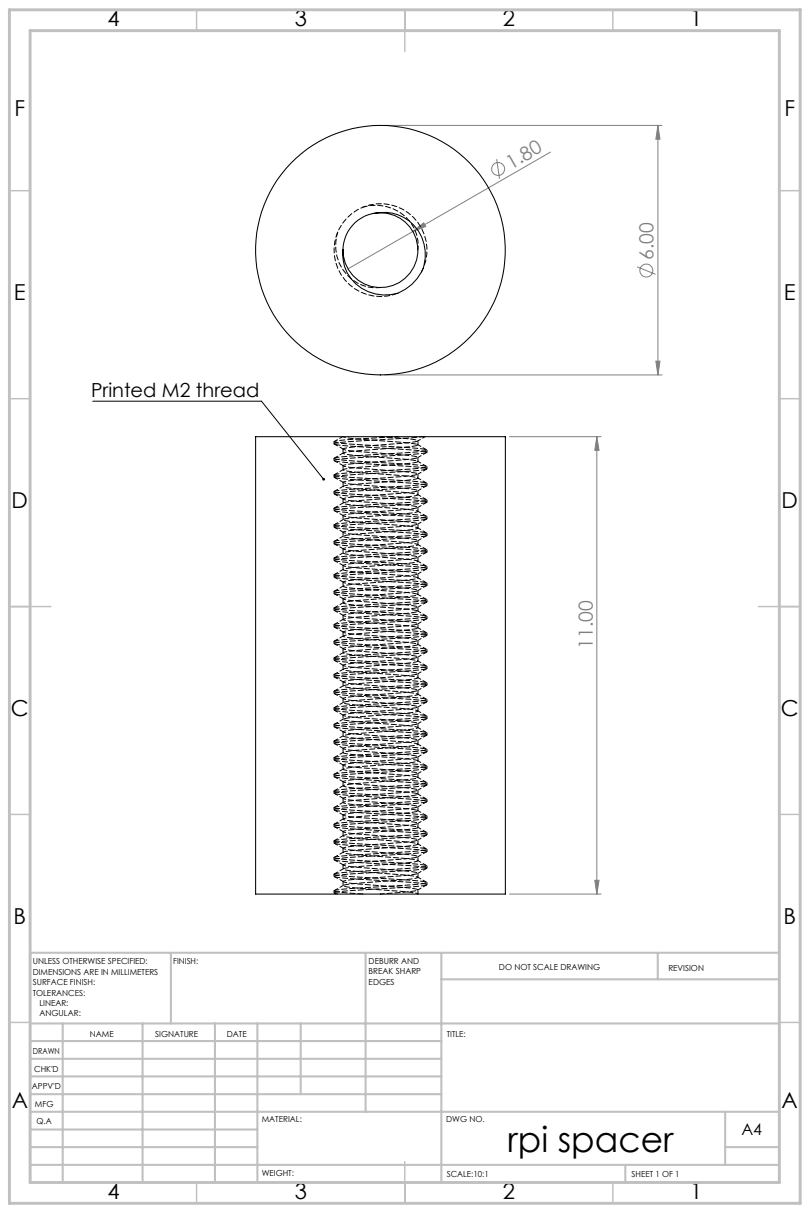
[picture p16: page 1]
Printed M2 thread; FINISH:; DEBURR AND; BREAK SHARP; DO NOT SCALE DRAWING; REVISION; SCALE:10:1; SHEET 1 OF 1

UNLESS OTHERWISE SPECIFIED:
DIMENSIONS ARE IN MILLIMETERS
SURFACE FINISH:
TOLERANCES:
LINEAR:
ANGULAR:

NAME | SIGNATURE | DATE | | | | TITLE:

DRAWN
CHK'D
APPV'D
MFG
Q.A | | | | MATERIAL: | DWG NO. rpi spacer | A4

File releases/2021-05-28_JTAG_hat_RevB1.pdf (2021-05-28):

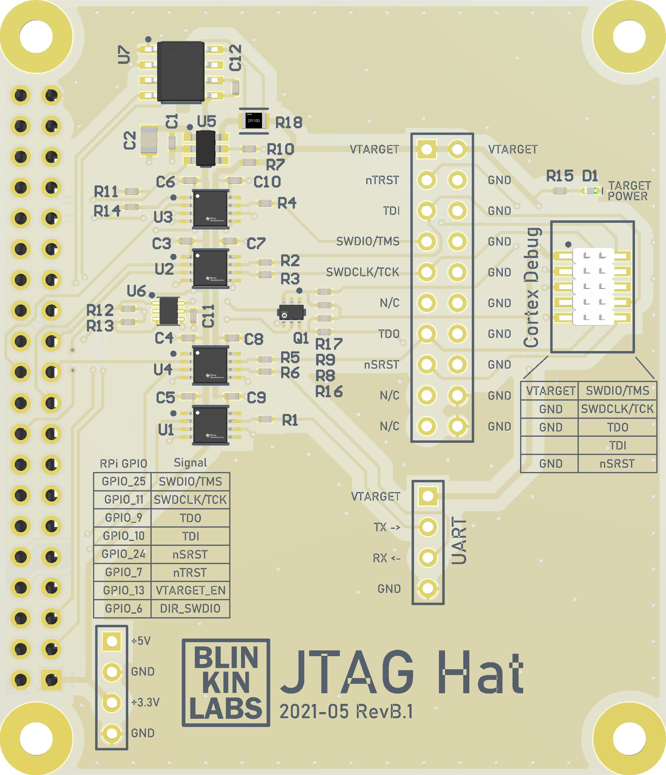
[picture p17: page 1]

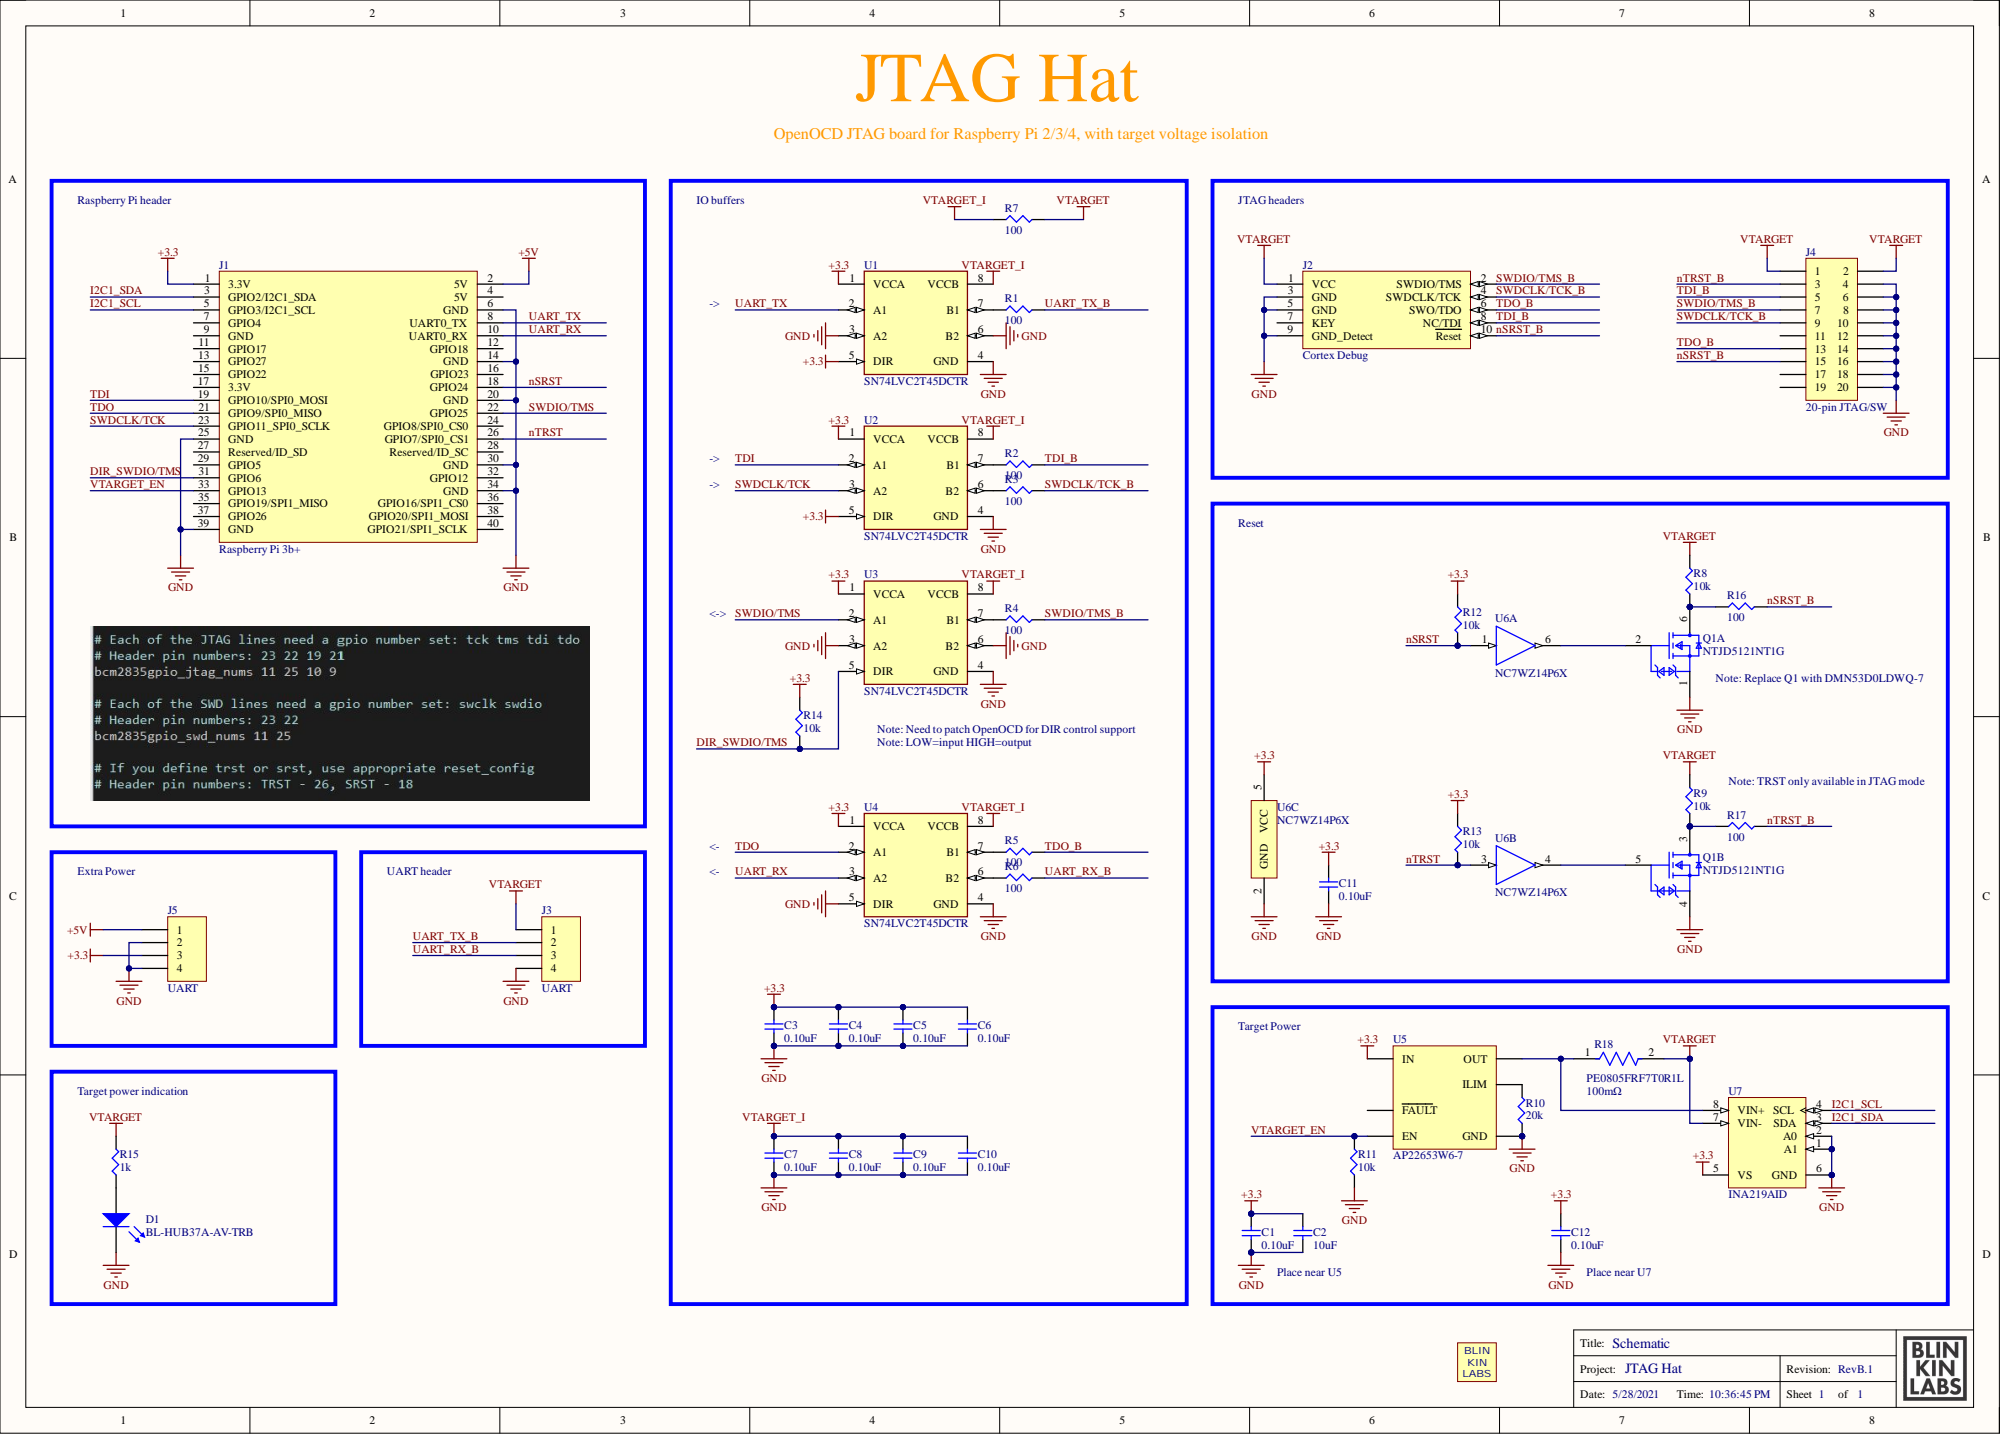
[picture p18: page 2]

OpenOCD JTAG board for Raspberry Pi 2/3/4, with target voltage isolation

Note: Need to patch OpenOCD for DIR control support
Note: LOW=input HIGH=output

Note: TRST only available in JTAG mode

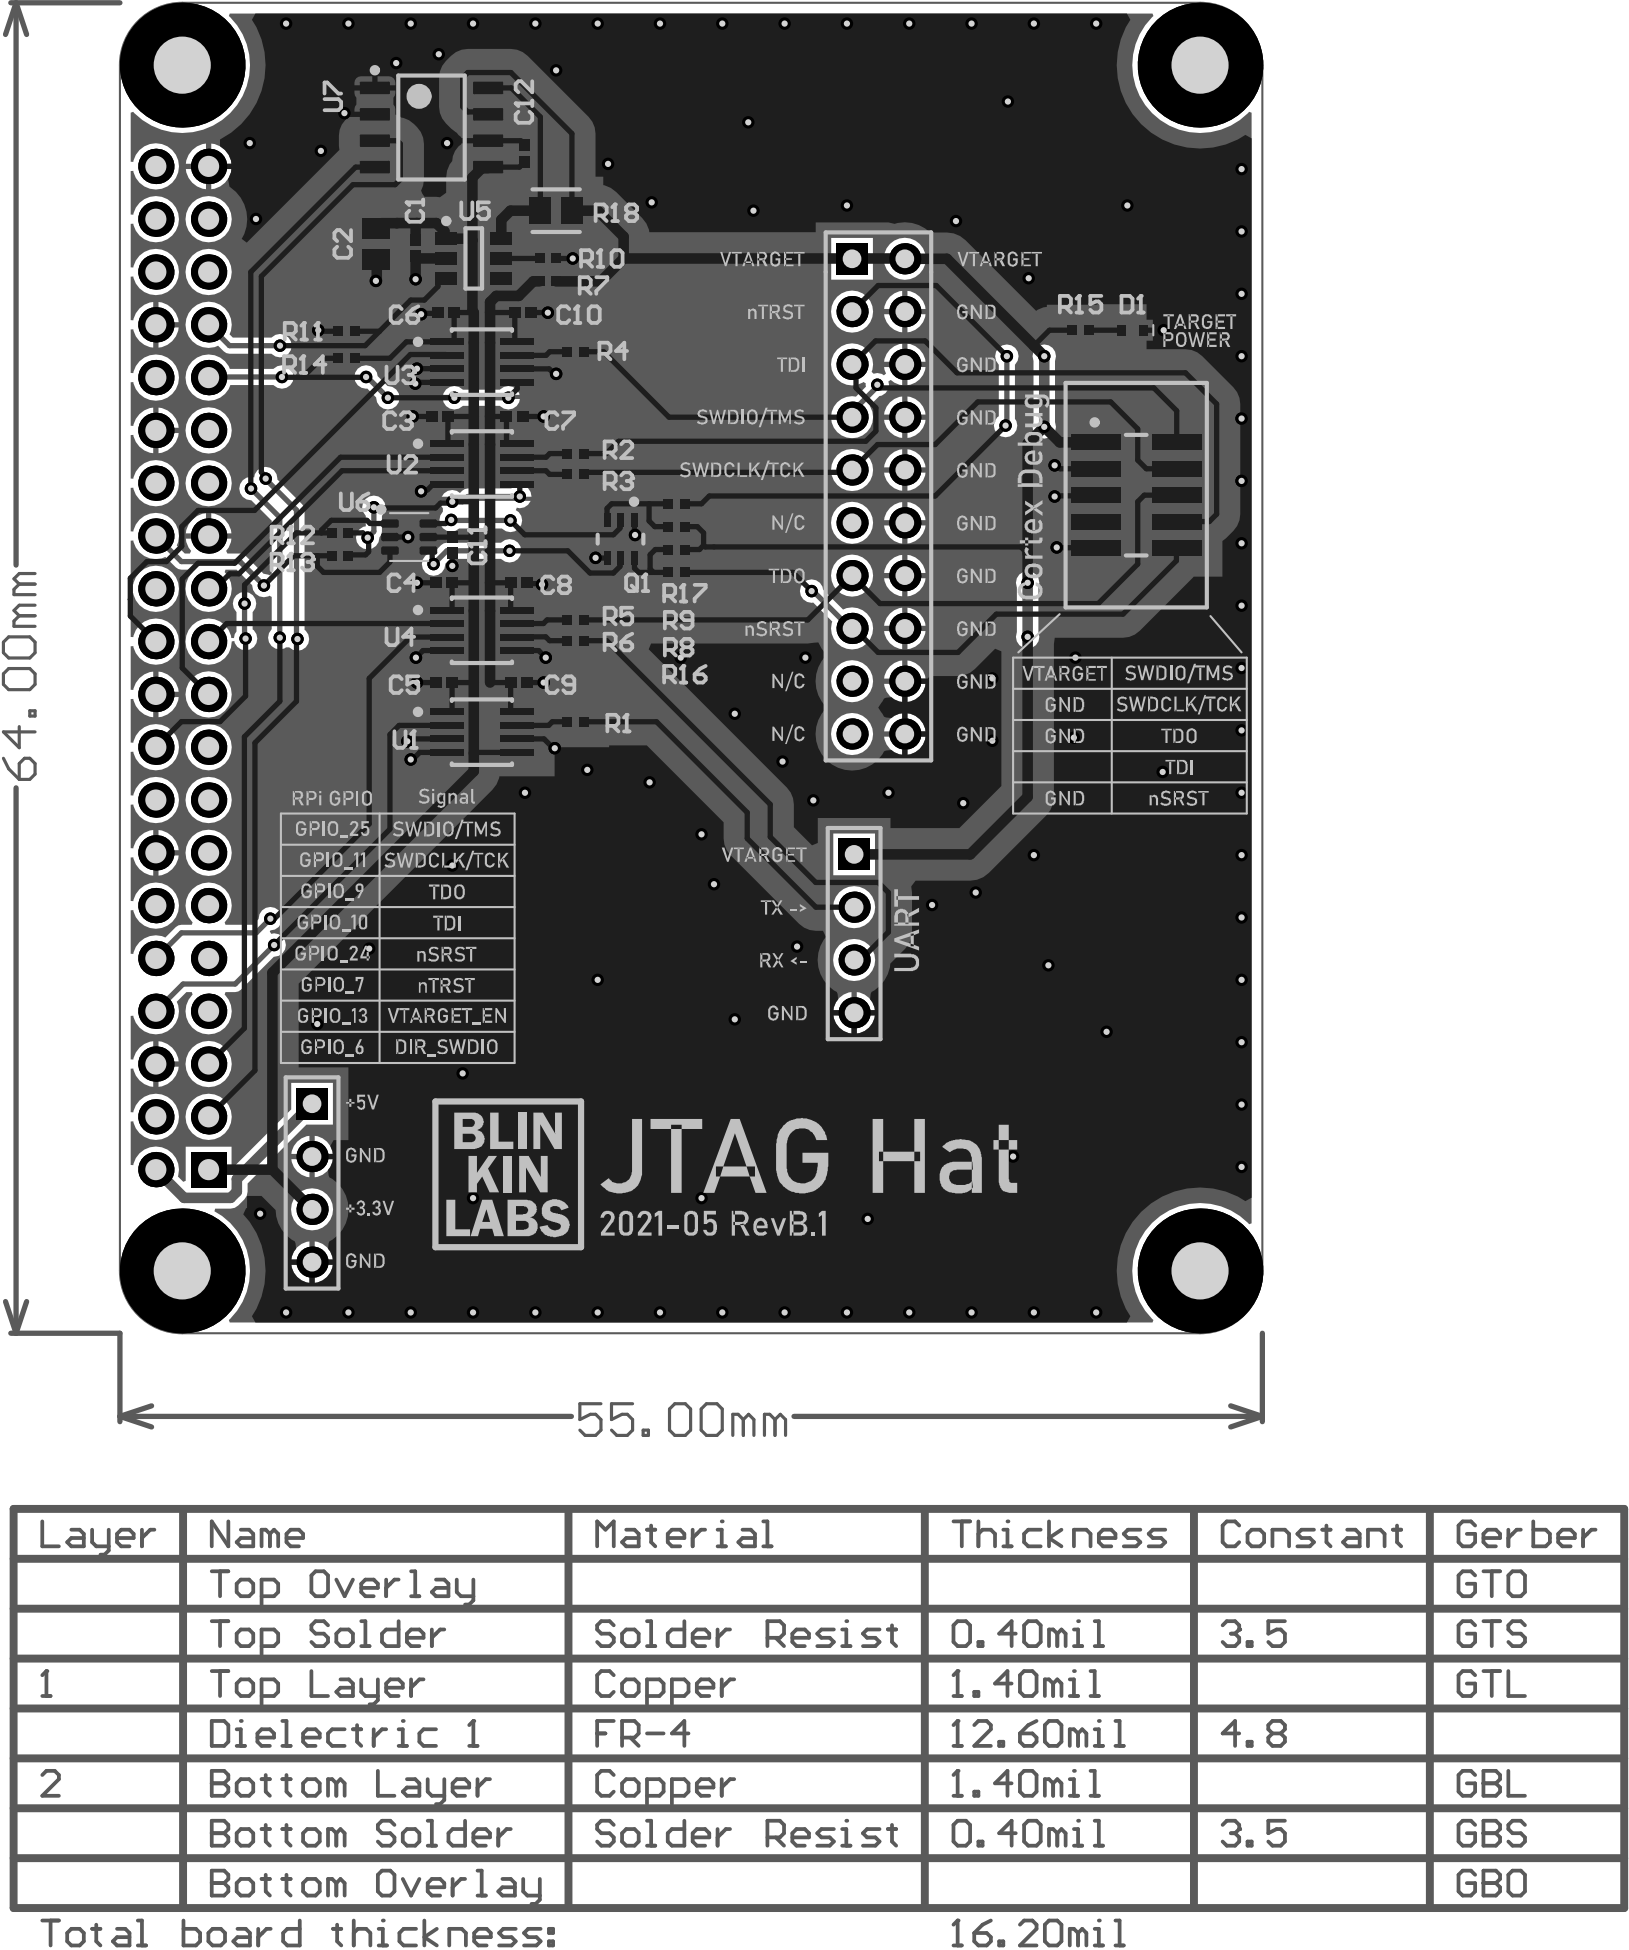
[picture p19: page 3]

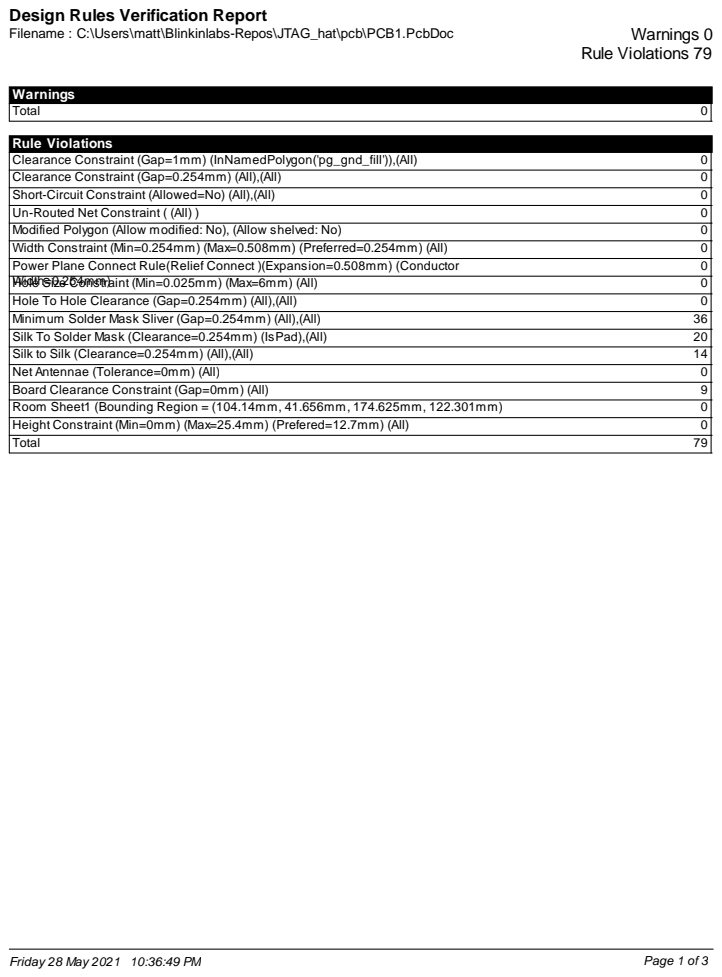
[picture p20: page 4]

Design Rules Verification Report

Rule Violations
Power Plane Connect Rule(Relief Connect )(Expansion=0.508mm) (Conductor
Width=0.254mm)

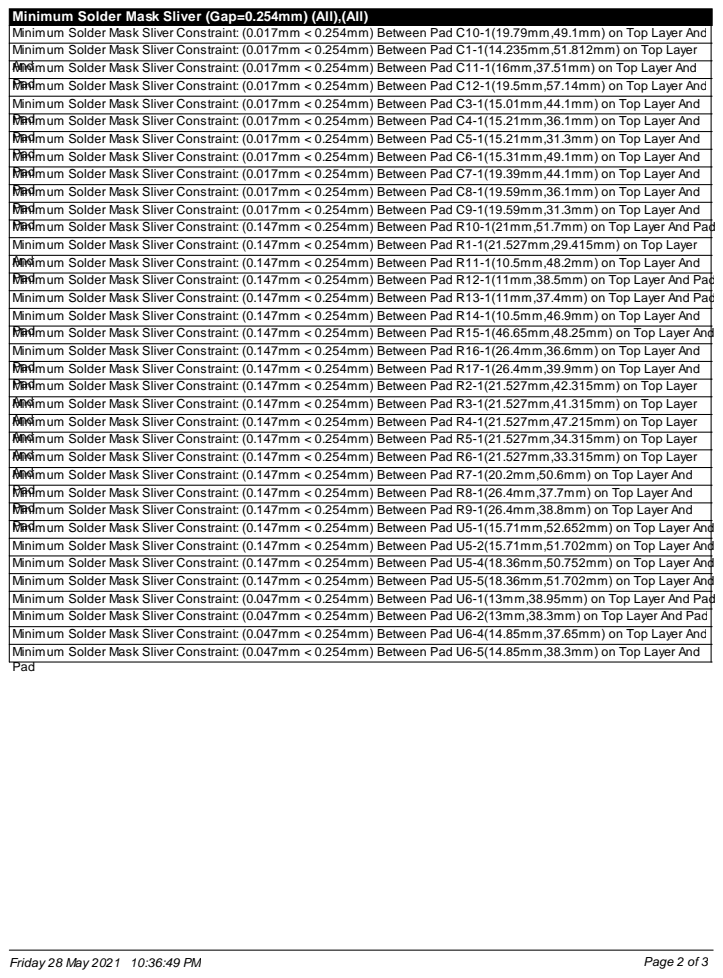
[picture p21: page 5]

Minimum Solder Mask Sliver (Gap=0.254mm) (All),(All)
Minimum Solder Mask Sliver Constraint: (0.017mm < 0.254mm) Between Pad C10-1(19.79mm,49.1mm) on Top Layer And
Minimum Solder Mask Sliver Constraint: (0.017mm < 0.254mm) Between Pad C1-1(14.235mm,51.812mm) on Top Layer
PaMindimum Solder Mask Sliver Constraint: (0.017mm < 0.254mm) Between Pad C12-1(19.5mm,57.14mm) on Top Layer And
Minimum Solder Mask Sliver Constraint: (0.017mm < 0.254mm) Between Pad C3-1(15.01mm,44.1mm) on Top Layer And
PaMindimum Solder Mask Sliver Constraint: (0.017mm < 0.254mm) Between Pad C4-1(15.21mm,36.1mm) on Top Layer And
PaMindimum Solder Mask Sliver Constraint: (0.017mm < 0.254mm) Between Pad C5-1(15.21mm,31.3mm) on Top Layer And
PaMindimum Solder Mask Sliver Constraint: (0.017mm < 0.254mm) Between Pad C6-1(15.31mm,49.1mm) on Top Layer And
PaMindimum Solder Mask Sliver Constraint: (0.017mm < 0.254mm) Between Pad C7-1(19.39mm,44.1mm) on Top Layer And
PaMindimum Solder Mask Sliver Constraint: (0.017mm < 0.254mm) Between Pad C8-1(19.59mm,36.1mm) on Top Layer And
PaMindimum Solder Mask Sliver Constraint: (0.017mm < 0.254mm) Between Pad C9-1(19.59mm,31.3mm) on Top Layer And
PaMindimum Solder Mask Sliver Constraint: (0.147mm < 0.254mm) Between Pad R10-1(21mm,51.7mm) on Top Layer And Pad
Minimum Solder Mask Sliver Constraint: (0.147mm < 0.254mm) Between Pad R1-1(21.527mm,29.415mm) on Top Layer
PaMindimum Solder Mask Sliver Constraint: (0.147mm < 0.254mm) Between Pad R12-1(11mm,38.5mm) on Top Layer And Pad
Minimum Solder Mask Sliver Constraint: (0.147mm < 0.254mm) Between Pad R13-1(11mm,37.4mm) on Top Layer And Pad
Minimum Solder Mask Sliver Constraint: (0.147mm < 0.254mm) Between Pad R14-1(10.5mm,46.9mm) on Top Layer And
PaMindimum Solder Mask Sliver Constraint: (0.147mm < 0.254mm) Between Pad R15-1(46.65mm,48.25mm) on Top Layer And
Minimum Solder Mask Sliver Constraint: (0.147mm < 0.254mm) Between Pad R16-1(26.4mm,36.6mm) on Top Layer And
PaMindimum Solder Mask Sliver Constraint: (0.147mm < 0.254mm) Between Pad R17-1(26.4mm,39.9mm) on Top Layer And
PaMindimum Solder Mask Sliver Constraint: (0.147mm < 0.254mm) Between Pad R2-1(21.527mm,42.315mm) on Top Layer
PaMindimum Solder Mask Sliver Constraint: (0.147mm < 0.254mm) Between Pad R8-1(26.4mm,37.7mm) on Top Layer And
PaMindimum Solder Mask Sliver Constraint: (0.147mm < 0.254mm) Between Pad R9-1(26.4mm,38.8mm) on Top Layer And
PaMindimum Solder Mask Sliver Constraint: (0.147mm < 0.254mm) Between Pad U5-1(15.71mm,52.652mm) on Top Layer And
Minimum Solder Mask Sliver Constraint: (0.147mm < 0.254mm) Between Pad U5-2(15.71mm,51.702mm) on Top Layer And
Minimum Solder Mask Sliver Constraint: (0.147mm < 0.254mm) Between Pad U5-4(18.36mm,50.752mm) on Top Layer And
Minimum Solder Mask Sliver Constraint: (0.147mm < 0.254mm) Between Pad U5-5(18.36mm,51.702mm) on Top Layer And
Minimum Solder Mask Sliver Constraint: (0.047mm < 0.254mm) Between Pad U6-1(13mm,38.95mm) on Top Layer And Pad
Minimum Solder Mask Sliver Constraint: (0.047mm < 0.254mm) Between Pad U6-2(13mm,38.3mm) on Top Layer And Pad
Minimum Solder Mask Sliver Constraint: (0.047mm < 0.254mm) Between Pad U6-4(14.85mm,37.65mm) on Top Layer And
Minimum Solder Mask Sliver Constraint: (0.047mm < 0.254mm) Between Pad U6-5(14.85mm,38.3mm) on Top Layer And
Pad

Mnindimum Solder Mask Sliver Constraint: (0.017mm < 0.254mm) Between Pad C11-1(16mm,37.51mm) on Top Layer And

Mnindimum Solder Mask Sliver Constraint: (0.147mm < 0.254mm) Between Pad R11-1(10.5mm,48.2mm) on Top Layer And

Mnindimum Solder Mask Sliver Constraint: (0.147mm < 0.254mm) Between Pad R3-1(21.527mm,41.315mm) on Top Layer
Mnindimum Solder Mask Sliver Constraint: (0.147mm < 0.254mm) Between Pad R4-1(21.527mm,47.215mm) on Top Layer
Mnindimum Solder Mask Sliver Constraint: (0.147mm < 0.254mm) Between Pad R5-1(21.527mm,34.315mm) on Top Layer
Mnindimum Solder Mask Sliver Constraint: (0.147mm < 0.254mm) Between Pad R6-1(21.527mm,33.315mm) on Top Layer
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

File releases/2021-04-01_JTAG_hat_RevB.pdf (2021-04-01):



OpenOCD JTAG board for Raspberry Pi 2/3/4, with target voltage isolation

Note: Need to patch OpenOCD for DIR control support
Note: LOW=input HIGH=output

Note: TRST only available in JTAG mode



Design Rules Verification Report

Rule Violations
Power Plane Connect Rule(Relief Connect )(Expansion=0.508mm) (Conductor
Width=0.254mm)


Minimum Solder Mask Sliver (Gap=0.254mm) (All),(All)
Minimum Solder Mask Sliver Constraint: (0.017mm < 0.254mm) Between Pad C10-1(19.79mm,49.1mm) on Top Layer And
Minimum Solder Mask Sliver Constraint: (0.017mm < 0.254mm) Between Pad C1-1(14.235mm,51.812mm) on Top Layer
PaMindimum Solder Mask Sliver Constraint: (0.017mm < 0.254mm) Between Pad C12-1(18.713mm,58.95mm) on Top Layer
PaMindimum Solder Mask Sliver Constraint: (0.017mm < 0.254mm) Between Pad C4-1(15.21mm,36.1mm) on Top Layer And
PaMindimum Solder Mask Sliver Constraint: (0.017mm < 0.254mm) Between Pad C5-1(15.21mm,31.3mm) on Top Layer And
PaMindimum Solder Mask Sliver Constraint: (0.017mm < 0.254mm) Between Pad C6-1(15.31mm,49.1mm) on Top Layer And
PaMindimum Solder Mask Sliver Constraint: (0.017mm < 0.254mm) Between Pad C7-1(19.39mm,44.1mm) on Top Layer And
PaMindimum Solder Mask Sliver Constraint: (0.017mm < 0.254mm) Between Pad C8-1(19.59mm,36.1mm) on Top Layer And
PaMindimum Solder Mask Sliver Constraint: (0.017mm < 0.254mm) Between Pad C9-1(19.59mm,31.3mm) on Top Layer And
PaMindimum Solder Mask Sliver Constraint: (0.147mm < 0.254mm) Between Pad R10-1(21mm,51.7mm) on Top Layer And Pad
Minimum Solder Mask Sliver Constraint: (0.147mm < 0.254mm) Between Pad R1-1(21.527mm,29.415mm) on Top Layer
PaMindimum Solder Mask Sliver Constraint: (0.147mm < 0.254mm) Between Pad R12-1(11mm,38.5mm) on Top Layer And Pad
Minimum Solder Mask Sliver Constraint: (0.147mm < 0.254mm) Between Pad R13-1(11mm,37.4mm) on Top Layer And Pad
Minimum Solder Mask Sliver Constraint: (0.147mm < 0.254mm) Between Pad R14-1(10.5mm,46.9mm) on Top Layer And
PaMindimum Solder Mask Sliver Constraint: (0.147mm < 0.254mm) Between Pad R15-1(46.65mm,48.25mm) on Top Layer And
Minimum Solder Mask Sliver Constraint: (0.147mm < 0.254mm) Between Pad R16-1(26.4mm,36.6mm) on Top Layer And
PaMindimum Solder Mask Sliver Constraint: (0.147mm < 0.254mm) Between Pad R17-1(26.4mm,39.9mm) on Top Layer And
PaMindimum Solder Mask Sliver Constraint: (0.147mm < 0.254mm) Between Pad R2-1(21.527mm,42.315mm) on Top Layer
PaMindimum Solder Mask Sliver Constraint: (0.147mm < 0.254mm) Between Pad R8-1(26.4mm,37.7mm) on Top Layer And
PaMindimum Solder Mask Sliver Constraint: (0.147mm < 0.254mm) Between Pad R9-1(26.4mm,38.8mm) on Top Layer And
PaMindimum Solder Mask Sliver Constraint: (0.147mm < 0.254mm) Between Pad U5-1(15.71mm,52.652mm) on Top Layer And
Minimum Solder Mask Sliver Constraint: (0.147mm < 0.254mm) Between Pad U5-2(15.71mm,51.702mm) on Top Layer And
Minimum Solder Mask Sliver Constraint: (0.147mm < 0.254mm) Between Pad U5-4(18.36mm,50.752mm) on Top Layer And
Minimum Solder Mask Sliver Constraint: (0.147mm < 0.254mm) Between Pad U5-5(18.36mm,51.702mm) on Top Layer And
Minimum Solder Mask Sliver Constraint: (0.047mm < 0.254mm) Between Pad U6-1(13mm,38.95mm) on Top Layer And Pad
Minimum Solder Mask Sliver Constraint: (0.047mm < 0.254mm) Between Pad U6-2(13mm,38.3mm) on Top Layer And Pad
Minimum Solder Mask Sliver Constraint: (0.047mm < 0.254mm) Between Pad U6-4(14.85mm,37.65mm) on Top Layer And
Minimum Solder Mask Sliver Constraint: (0.047mm < 0.254mm) Between Pad U6-5(14.85mm,38.3mm) on Top Layer And
Pad

Mnindimum Solder Mask Sliver Constraint: (0.017mm < 0.254mm) Between Pad C11-1(16mm,37.51mm) on Top Layer And

Mnindimum Solder Mask Sliver Constraint: (0.017mm < 0.254mm) Between Pad C3-1(15.01mm,44.1mm) on Top Layer And

Mnindimum Solder Mask Sliver Constraint: (0.147mm < 0.254mm) Between Pad R11-1(10.5mm,48.2mm) on Top Layer And

Mnindimum Solder Mask Sliver Constraint: (0.147mm < 0.254mm) Between Pad R3-1(21.527mm,41.315mm) on Top Layer
Mnindimum Solder Mask Sliver Constraint: (0.147mm < 0.254mm) Between Pad R4-1(21.527mm,47.215mm) on Top Layer
Mnindimum Solder Mask Sliver Constraint: (0.147mm < 0.254mm) Between Pad R5-1(21.527mm,34.315mm) on Top Layer
Mnindimum Solder Mask Sliver Constraint: (0.147mm < 0.254mm) Between Pad R6-1(21.527mm,33.315mm) on Top Layer
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

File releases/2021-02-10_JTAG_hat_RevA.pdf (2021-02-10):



OpenOCD JTAG board for Raspberry Pi 2/3/4, with target voltage isolation

Note: Need to patch OpenOCD for DIR control support
Note: LOW=input HIGH=output

Note: TRST only available in JTAG mode



Design Rules Verification Report

Rule Violations
Power Plane Connect Rule(Relief Connect )(Expansion=0.508mm) (Conductor
Width=0.254mm)

Clearance Constraint (Gap=0.254mm) (All),(All)
Clearance Constraint: (0.22mm < 0.254mm) Between Pad C10-1(19.79mm,49.1mm) on Top Layer And Pad
Clearance Constraint: (0.22mm < 0.254mm) Between Pad C1-1(14.235mm,51.812mm) on Top Layer And Pad
Clearance Constraint: (0.22mm < 0.254mm) Between Pad C3-1(15.01mm,44.1mm) on Top Layer And Pad
Clearance Constraint: (0.22mm < 0.254mm) Between Pad C4-1(15.21mm,36.1mm) on Top Layer And Pad
Clearance Constraint: (0.22mm < 0.254mm) Between Pad C5-1(15.21mm,31.3mm) on Top Layer And Pad
Clearance Constraint: (0.22mm < 0.254mm) Between Pad C6-1(15.31mm,49.1mm) on Top Layer And Pad
Clearance Constraint: (0.22mm < 0.254mm) Between Pad C7-1(19.39mm,44.1mm) on Top Layer And Pad
Clearance Constraint: (0.22mm < 0.254mm) Between Pad C8-1(19.59mm,36.1mm) on Top Layer And Pad
Clearance Constraint: (0.22mm < 0.254mm) Between Pad C9-1(19.59mm,31.3mm) on Top Layer And Pad


Minimum Solder Mask Sliver (Gap=0.254mm) (All),(All)
Minimum Solder Mask Sliver Constraint: (0.017mm < 0.254mm) Between Pad C10-1(19.79mm,49.1mm) on Top Layer And
Minimum Solder Mask Sliver Constraint: (0.017mm < 0.254mm) Between Pad C1-1(14.235mm,51.812mm) on Top Layer
PaMindimum Solder Mask Sliver Constraint: (0.017mm < 0.254mm) Between Pad C4-1(15.21mm,36.1mm) on Top Layer And
PaMindimum Solder Mask Sliver Constraint: (0.017mm < 0.254mm) Between Pad C5-1(15.21mm,31.3mm) on Top Layer And
PaMindimum Solder Mask Sliver Constraint: (0.017mm < 0.254mm) Between Pad C6-1(15.31mm,49.1mm) on Top Layer And
PaMindimum Solder Mask Sliver Constraint: (0.017mm < 0.254mm) Between Pad C7-1(19.39mm,44.1mm) on Top Layer And
PaMindimum Solder Mask Sliver Constraint: (0.017mm < 0.254mm) Between Pad C8-1(19.59mm,36.1mm) on Top Layer And
PaMindimum Solder Mask Sliver Constraint: (0.017mm < 0.254mm) Between Pad C9-1(19.59mm,31.3mm) on Top Layer And
PaMindimum Solder Mask Sliver Constraint: (0.147mm < 0.254mm) Between Pad R10-1(19.835mm,53.102mm) on Top Layer
PaMindimum Solder Mask Sliver Constraint: (0.147mm < 0.254mm) Between Pad R12-1(21.5mm,38.8mm) on Top Layer And
PaMindimum Solder Mask Sliver Constraint: (0.147mm < 0.254mm) Between Pad R13-1(21.5mm,37.7mm) on Top Layer And
PaMindimum Solder Mask Sliver Constraint: (0.147mm < 0.254mm) Between Pad R14-1(10.5mm,46.9mm) on Top Layer And
PaMindimum Solder Mask Sliver Constraint: (0.147mm < 0.254mm) Between Pad R15-1(46.65mm,48.25mm) on Top Layer And
Minimum Solder Mask Sliver Constraint: (0.147mm < 0.254mm) Between Pad R16-1(26.4mm,36.6mm) on Top Layer And
PaMindimum Solder Mask Sliver Constraint: (0.147mm < 0.254mm) Between Pad R17-1(26.4mm,39.9mm) on Top Layer And
PaMindimum Solder Mask Sliver Constraint: (0.147mm < 0.254mm) Between Pad R2-1(21.527mm,42.315mm) on Top Layer
PaMindimum Solder Mask Sliver Constraint: (0.147mm < 0.254mm) Between Pad R8-1(26.4mm,37.7mm) on Top Layer And
PaMindimum Solder Mask Sliver Constraint: (0.147mm < 0.254mm) Between Pad R9-1(26.4mm,38.8mm) on Top Layer And
PaMindimum Solder Mask Sliver Constraint: (0.147mm < 0.254mm) Between Pad U5-1(15.71mm,52.652mm) on Top Layer And
Minimum Solder Mask Sliver Constraint: (0.147mm < 0.254mm) Between Pad U5-2(15.71mm,51.702mm) on Top Layer And
Minimum Solder Mask Sliver Constraint: (0.147mm < 0.254mm) Between Pad U5-4(18.36mm,50.752mm) on Top Layer And
Minimum Solder Mask Sliver Constraint: (0.147mm < 0.254mm) Between Pad U5-5(18.36mm,51.702mm) on Top Layer And

Mnindimum Solder Mask Sliver Constraint: (0.017mm < 0.254mm) Between Pad C3-1(15.01mm,44.1mm) on Top Layer And

Mnindimum Solder Mask Sliver Constraint: (0.147mm < 0.254mm) Between Pad R1-1(21.527mm,29.415mm) on Top Layer
Mnindimum Solder Mask Sliver Constraint: (0.147mm < 0.254mm) Between Pad R11-1(10.5mm,48.2mm) on Top Layer And
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

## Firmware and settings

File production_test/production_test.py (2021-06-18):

#!/usr/bin/python3
import ina219
import gpiozero
import time
import serial
import subprocess

results = {}
results['pass'] = 0
results['fail'] = 0

SHUNT_OHMS = 0.1

def read_power():
    results = {}
    results['voltage'] = ina.voltage()
    results['current'] = ina.current()
    return results

# Current sensor
ina = ina219.INA219(SHUNT_OHMS)
ina.configure()

# VTarget enable
vtarget_en = gpiozero.LED(13)
vtarget_en.off()
time.sleep(1)

# buffered UART
uart = serial.Serial("/dev/serial0", 115200, timeout=.2)


# Test that no voltage is present while off
val = read_power()
print(val)
if (val['voltage'] > .05):
    print('target voltage (off) fail')
    results['fail'] += 1
else:
    print('target voltage (off) ok')
    results['pass'] += 1

if (val['current'] > .05):
    print('target current (off) fail')
    results['fail'] += 1
else:
    print('target current (off) ok')
    results['pass'] += 1

# Test that serial doesn't work while off
uart.write(b"hey")
val = uart.read(3)
print({val})
if val != b"":
    print('UART RX(off) fail')
    results['fail'] += 1
else:
    print('UART RX(off) ok')
    results['pass'] += 1


# Enable power
vtarget_en.on()
time.sleep(1)

# Test that voltage and current present while on
val = read_power()
print(val)
if (val['voltage'] > 3.4) or (val['voltage'] < 3.2):
    print('target voltage (on) fail')
    results['fail'] += 1
else:
    print('target voltage (on) ok')
    results['pass'] += 1

if (val['current'] > 100) or (val['current'] < 40):
    print('target current (on) fail')
    results['fail'] += 1
else:
    print('target current (on) ok')
    results['pass'] += 1

# Test that serial loopback works while on (requires jumper from TX to RX)
uart.write(b"hey")
val = uart.read(3)
print({val})
if val != b"hey":
    print('UART RX(on) fail')
    results['fail'] += 1
else:
    print('UART RX(on) ok')
    results['pass'] += 1

# Test that a target can be probed using JTAG
command = [
  "sudo",
  "openocd",
  "-f", "jtag_hat.cfg",
  "-c", "bindto 0.0.0.0; transport select jtag",
  "-c", "adapter speed 1000",
  "-f", "target/stm32f1x.cfg",
  "-c", "init; exit"
  ]

s = open('result-jtag.log','w')
e = open('errorresult-jtag.log','w')
val = subprocess.call(command, stdout=s, stderr=e)
s.close()
e.close()
if (val != 0):
    print('JTAG test fail')
    results['fail'] += 1
else:
    print('JTAG test ok')
    results['pass'] += 1


# Test that a target can be probed using SWD
command = [
  "sudo",
  "openocd",
  "-f", "jtag_hat.cfg",
  "-c", "bindto 0.0.0.0; transport select swd",
  "-c", "adapter speed 1000",
  "-f", "target/stm32f1x.cfg",
  "-c", "init; exit"
  ]


s = open('result-swd.log','w')
e = open('errorresult-swd.log','w')
val = subprocess.call(command, stdout=s, stderr=e)
s.close()
e.close()
if (val != 0):
    print('SWD test fail')
    results['fail'] += 1
else:
    print('SWD test ok')
    results['pass'] += 1


print(results)

print('test done, running reset toggle for manual verification')

srst = gpiozero.LED(24)
trst = gpiozero.LED(7)

while True:
    trst.on()
    srst.off()
    time.sleep(.5)
    trst.off()
    srst.on()
    time.sleep(.5)

# Disable power
vtarget_en.off()

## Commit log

2021-01-21 First release, RevA
    [2021-01-21_JTAG_Hat_RevA BOM.xlsx, 2021-01-21_JTAG_Hat_RevA Pick Place.csv, JTAG_hat.PrjPcb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]
2021-02-10 Add bypass caps
    [2021-01-21_JTAG_Hat_RevA BOM.xlsx, 2021-01-21_JTAG_Hat_RevA Pick Place.csv, 2021-02-10_JTAG_hat_RevA BOM.xlsx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]
2021-03-30 RevB update: add pinouts, power header
    [2021-03-30_JTAG_hat_RevB BOM.xlsx, 2021-03-30_JTAG_hat_RevB Pick Place.csv, JTAG_hat.PrjPcb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]
2021-04-01 RevB: Add INA219 current monitor
    [2021-03-30_JTAG_hat_RevB BOM.xlsx, 2021-03-30_JTAG_hat_RevB Pick Place.csv, 2021-04-01_JTAG_hat_RevB BOM.xlsx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]
2021-05-28 Update PCB to use different version of INA219
    [2021-05-28_JTAG_hat_RevB1 BOM.xlsx, 2021-05-28_JTAG_hat_RevB1 Pick Place.csv, JTAG_hat.PrjPcb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]
2021-06-18 Add production test script
    [jtag_hat.cfg]
2021-06-18 Add spacer design
    [2021-05-27_spacer.STL]
2022-01-31 Add updated spacer design
    [2022-01-30 spacer v1.f3d, 2022-01-30 spacer.3mf]
2024-08-18 Re-generate BOM in new format
    [2024-08-18_JTAG_hat_RevB1 BOM.csv, JTAG_hat.PrjPcb]
2024-09-09 Work on updating the BOM
    [JTAG_hat.PrjPcb, PCB1.PcbDoc, Sheet1.SchDoc]
2024-09-10 Release Rev B2, with more accurate BOM
    [2024-09-10_JTAG_hat_Revb2 BOM.csv, 2024-09-10_JTAG_hat_Revb2 Pick Place.csv, PCB1.PcbDoc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]
2024-09-10 Save project file
    [JTAG_hat.PrjPcb]
